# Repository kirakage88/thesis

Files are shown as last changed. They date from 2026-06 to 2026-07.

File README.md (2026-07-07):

# 🔧 Predictive Maintenance for Coiled Evaporators

> **Bachelor's Thesis** · Mechanical Engineering · Xavier University

---

## 💡 The Idea

Monitor aircon evaporator health in real time. Sensor data flows from ESP32 nodes through ESP-NOW to a TFT touchscreen, then up to the cloud. Machine learning models predict maintenance needs before failure hits.

---

## ⚡ How It Works

```
  🌡️ Sensors          📡 ESP-NOW           🖥️ TFT + ☁️ Cloud
  ┌──────────┐       ┌──────────┐        ┌──────────────┐
  │ BME280   │──────►│  Sender  │───────►│   Receiver   │
  │ DS18B20  │       │  ESP32   │  P2P   │  ESP32 + TFT │──► Supabase
  │ ×3 probes│       └──────────┘        └──────────────┘
  └──────────┘
```

**Ambient readings** (temp + humidity) + **3 probe temperatures** → calibrated → wireless → displayed + logged.

---

## 🗂️ Repo Map

```
thesis/
│
├── 📄 Thesis Proposal.pdf
│
├── 📂 codes/
│   ├── 📂 prototyping/                 # Final integrated builds
│   │   ├── ambient_module_final/       # Sensor fusion (BME280 + probes)
│   │   ├── now_ambient_sender/         # Wireless data transmitter
│   │   ├── now_receiver_supabase/      # Receiver + cloud pipeline
│   │   └── tft_complete/               # Display firmware (main UI)
│   │
│   ├── 📂 testing/                     # Component experiments
│   │   ├── BME280/  DS18B20/  probes/  i2c_scanner/
│   │   ├── now_sender/  now_receiver/  supabase/
│   │   ├── tft_display/  tft_touch/  tft_ui_demo/
│   │   └── ...                         # 15+ test sketches
│   │
│   └── 📂 python/machine learning/     # Classification experiments
│       ├── 0 perceptron.py
│       ├── 1 logistic_regression.py
│       ├── 2 SVM.py
│       ├── 3 dec_tree.py
│       ├── 4 random_forest.py
│       ├── 5 knn_classifier.py
│       └── pre-processing/
│
├── 📂 schematics/                      # Fritzing — circuits & PCBs
├── 📂 designs/                         # UI mockups, palette, fonts
└── 📂 resources/
```

---

## 🔌 Hardware

| Part | Interface | What It Does |
|---|---|---|
| ESP32-C3 Super Mini | — | Brains of the operation |
| BME280 | I2C (`0x76`) | Ambient temp + humidity |
| DS18B20 ×3 | OneWire (GPIO10) | Submerged probe temps |
| ST7789 240×320 TFT | SPI | Color display |
| XPT2046 | SPI (shared CLK) | Touch input |

### Calibration

```
BME280 Temp      →  raw × 1.0294412
BME280 Humidity  →  raw × 1.0579399
Probe A          →  1.701471 + 0.984997 × raw
Probe B / C      →  1.637417 + 0.9783362 × raw
```

---

## 🧠 Machine Learning

Six classifiers trained on sensor data — from classic Perceptron to Random Forest:

| # | Script | Model |
|---|---|---|
| 0 | `0 perceptron.py` | Perceptron |
| 1 | `1 logistic_regression.py` | Logistic Regression |
| 2 | `2 SVM.py` | Support Vector Machine |
| 3 | `3 dec_tree.py` | Decision Tree |
| 4 | `4 random_forest.py` | Random Forest |
| 5 | `5 knn_classifier.py` | K-Nearest Neighbors |

### Spin Up the Python Env

```bash
cd codes/python/machine learning

python -m venv .venv
# PowerShell:  .venv\Scripts\Activate.ps1
# Git Bash:    source .venv/Scripts/activate

pip install numpy matplotlib scikit-learn pandas

# Need deep learning later? Add PyTorch with CUDA:
pip install torch --index-url https://download.pytorch.org/whl/cu130
```

---

## 📐 Design

The TFT UI follows a **mobile-app navigation pattern** — persistent bottom bar, center arrow for a full-screen menu. Iron Grey palette with light/dark mode. Lora + Montserrat typography.

**Pages:** Main Menu → Pairing → Devices → Units → System

> Full mockups, palette shades, and component specs in `designs/tft_display/design_readme.md`.

---

## 🚀 Quick Start

**Firmware (Arduino)**
```bash
# 1. Arduino IDE + ESP32 board support
# 2. Install: TFT_eSPI, OneWire, DallasTemperature, Adafruit_BME280, esp_now, ESPSupabase
# 3. Open codes/prototyping/now_ambient_sender/
# 4. Board → ESP32-C3 Super Mini → Flash
```

**ML (Python)**
```bash
cd codes/python/machine learning
python -m venv .venv && source .venv/Scripts/activate
pip install numpy matplotlib scikit-learn pandas
python 0 perceptron.py
```

---

---

## 🛠️ Installation

**Git**
- Linux (Debian/Ubuntu): `sudo apt install git`
- macOS: `brew install git` or download from [git-scm.com](https://git-scm.com)
- ChromeOS: enable Linux (Crostini), then `sudo apt install git`
- Windows: download from [git-scm.com](https://git-scm.com)
- Verify: `git --version`

---

## ⚙️ Git Configuration

```bash
git config --global user.name "Your Name"
git config --global user.email "your_email@example.com"
git config --global init.defaultBranch main
```

- If using GitHub's privacy feature, use the provided private email: `username@users.noreply.github.com`
- Verify: `git config --global user.name` and `git config --global user.email`
- **macOS:** ignore `.DS_Store` files globally to prevent metadata files from appearing in commits:

```bash
echo ".DS_Store" >> ~/.gitignore_global
git config --global core.excludesFile ~/.gitignore_global
```

---

## 🌐 GitHub Account Setup

- Use a **real email** — required for contribution tracking
- Enable privacy settings: keep email private, block CLI pushes that expose personal email
- Enable **2FA** using a TOTP app (Google Authenticator, Authy, etc.)
  - ⚠️ **Warning:** losing 2FA credentials **and** recovery codes means permanent account lockout — GitHub Support cannot restore access

---

## 🔑 SSH Key Authentication

Check for an existing key:

```bash
ls ~/.ssh/id_ed25519.pub
```

Generate a new Ed25519 key:

```bash
ssh-keygen -t ed25519 -C "your_email@example.com"
```

- Press Enter to accept the default location
- Optional: set a passphrase for extra security

Copy the public key:

```bash
cat ~/.ssh/id_ed25519.pub
```

It starts with `ssh-ed25519` and ends with `username@hostname`.

**Add to GitHub:**
1. Settings → SSH and GPG keys → New SSH Key
2. Paste the public key as an **Authentication Key**

Test the connection:

```bash
ssh -T git@github.com
```

- Success: `"Hi username! You've successfully authenticated, but GitHub does not provide shell access."`
- Failure: retry or ask for help in TOP Discord

Multiple SSH keys can be linked to one GitHub account — one per machine.

---

*Built with ☕ and late nights by **Kira (JRon)** · JPSME-XUC · Xavier University*

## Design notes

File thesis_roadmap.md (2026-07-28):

# Thesis Roadmap — Predictive Maintenance for Coiled Evaporators

Group: John Ronald Pacaldo · Collin Brandon Asio · Simon France Sulibio

**Architecture Decision:** Unsupervised anomaly detection (primary) \+ supervised classification (secondary, conditional). \[See appendix for full A vs B analysis.\]

---

## Legend

| Emoji | Type |
| :---- | :---- |
| 📝 | Paper Overhaul |
| 🔧 | Prototyping |
| 💻 | Coding |
| 🤖 | Machine Learning |
| 📊 | Data Collection |
| 🚀 | Deployment |
| 📋 | Documentation |

| Priority | Symbol |
| :---- | :---- |
| Critical | 🔴 |
| High | 🟠 |
| Medium | 🟡 |
| Low | 🟢 |

| Status | Symbol |
| :---- | :---- |
| Not started | ⬜ |
| In progress | 🔄 |
| Blocked | 🚫 |
| Completed | ✅ |

---

## Phase 1 — Paper Overhaul: Foundation

**Goal:** Rewrite Chapter 1 and pre-prototyping sections of Chapter 3 to reflect the reframed thesis: non-invasive anomaly detection as a complementary triage tool for scheduled preventive maintenance. Lock down the architecture before any hardware work.

### Chapter 1 — Introduction

- [x] 🔴 **Rewrite the thesis title** — `1.1 JOHN PACALDO`  
        
- [x] 🔴 **Rewrite the research gap** — `1.1 JOHN PACALDO`  
        
      \- \*\*Old:\*\* "No localized data-driven early warning exists; current maintenance is insufficient."    
        
      \- \*\*New:\*\* "Scheduled preventive maintenance ensures regular cleaning every 3–4 months, but the interval between services creates an information gap: maintenance staff cannot reliably identify which specific units are experiencing early-stage performance degradation between visits without physical disassembly. This study investigates whether a non-invasive sensor system — using only external temperature, electrical, and vibration measurements, with no evaporator access — can detect anomalous operating behavior, serving as a complementary triage tool to existing preventive maintenance at Xavier University. As Xavier University develops its Campus of the Future, this study serves as a proof-of-concept for site-specific, non-invasive AC condition monitoring."  
        
- [ ] 🔴 **Fix variable-sensor mapping** — `1.4 Conceptual Framework SIMON SULIBIO`  
        
      \- Remove: refrigerant leaks (no gas sensor), ice build-up (non-invasive access constraint), ESP32-CAM (cannot open evaporator)    
        
      \- Rename: "noise" → "vibration" (MPU6050 accelerometer)    
        
      \- Add: set temperature (manually recorded from thermostat/remote during each visit) — provides baseline for comparing actual vs. target cooling performance    
        
      \- Create explicit mapping table: Independent Variable → Sensor → Data Type → Model Input    
        
      \- Redraw conceptual framework diagram to match actual hardware and non-invasive approach  
        
- [ ] 🔴 **Add operational definition of Normal/Abnormal** — `1.1 / 3.1 COLLIN ASIO`  
        
      \- A unit is \*\*Normal\*\* if it exhibits acceptable cooling performance, no abnormal vibration or electrical behavior during inspection, and no maintenance concern is documented in the PPO maintenance logs.    
        
      \- A unit is \*\*Degraded\*\* if technician inspection identifies performance degradation, abnormal electrical or vibration characteristics, or a maintenance record documents a fault requiring corrective action.  
        
- [ ] 🔴 **Rewrite research questions for unsupervised focus** *`JOHN PACALDO`*  
        
      \- \*\*RQ1:\*\* Which non-invasive sensor measurements (supply-return temperature differential, compressor/fan current signatures, vibration spectral features) demonstrate the strongest discriminatory power for distinguishing normal from degraded unit behavior, as measured by feature importance and anomaly score separation?    
        
      \- \*\*RQ2:\*\* Which unsupervised anomaly detection model (Autoencoder, Isolation Forest, One-Class SVM, Gaussian Mixture Model) most reliably identifies AC units exhibiting anomalous operating signatures, validated through retrospective log comparison and controlled fault injection?    
        
      \- \*\*RQ3 (conditional):\*\* Does replacing raw environmental sensor features with a composite thermal comfort metric (PMV) improve anomaly detection sensitivity, provided the DIY airflow sensor is successfully developed?    
        
      \- \*\*RQ4:\*\* Does anomaly score generalize across AC units not seen during model development (unit-level evaluation), and does time-since-last-cleaning confound anomaly detection?  
        
- [ ] 🔴 **Rewrite hypotheses (falsifiable with margins and tests)** *`JOHN PACALDO`*  
        
      Each RQ has at least one hypothesis. Tests: Mann-Whitney U (p\<0.05) for group separation; paired bootstrap (p\<0.05) for feature contribution; TPR threshold for raw detection rate; within 3pp/5pp for performance margins; McNemar's (p\>0.05) for model equivalence; Spearman's ρ (p\>0.05) for confound correlation; ANOVA (p\>0.05) for kit-to-kit consistency.  
        
      \*\*RQ1 — Sensor measurement discriminatory power:\*\*  
        
      \- \*\*H1a:\*\* At least one sensor measurement group (supply-return temperature differential, compressor/fan current signatures, vibration spectral features) demonstrates statistically significant anomaly score separation between known-fault and known-healthy units (p \< 0.05, Mann-Whitney U test).  
        
      \- \*\*H1b:\*\* Vibration-derived features (spectrogram CNN output or statistical features) contribute statistically significant improvement to anomaly detection over temperature-and-electrical-only features (p \< 0.05, paired bootstrap).  
        
      \*\*RQ2 — Unsupervised model performance:\*\*  
        
      \- \*\*H2a:\*\* At least one unsupervised model (Autoencoder, Isolation Forest, One-Class SVM, Gaussian Mixture Model) achieves anomaly score separation between known-fault and known-healthy units (p \< 0.05, Mann-Whitney U test) AND true positive rate ≥ 80% on injected faults.  
        
      \- \*\*H2b:\*\* PCA-reduced features achieve anomaly detection performance within 3 percentage points of the full feature set AND show no statistically significant difference in unit-level anomaly ranking (p \> 0.05, McNemar's test).  
        
      \*\*RQ3 — Composite thermal comfort metric (conditional):\*\*  
        
      \- \*\*H3 (conditional):\*\* Replacing raw environmental sensor features with a single PMV composite metric does not significantly degrade anomaly detection performance (within 3pp of raw-feature baseline).  
        
      \*\*RQ4 — Generalization and confound verification:\*\*  
        
      \- \*\*H4a:\*\* Anomaly score separation on held-out units (Leave-One-Unit-Out evaluation) remains within 5 percentage points of in-sample performance (McNemar's test, p \> 0.05).  
        
      \- \*\*H4b:\*\* Time-since-last-cleaning and ambient environmental variables (temperature, humidity) show no statistically significant correlation with anomaly score (p \> 0.05, Spearman's ρ), and kit ID does not predict anomaly score (p \> 0.05, ANOVA).  
        
      \*\*Hypothesis Execution Order & Dependencies\*\* (for planning; draft stays in RQ reading order):  
        
      \*\*First to test — H1a (gate):\*\* If no sensor group separates known-fault from known-healthy, the entire sensor suite is in question. Test with a baseline model \+ Layer 1 retrospective data before investing in Phase 7 CNN / PCA / PMV.  
        
      | \# | H | Prerequisite | Earliest phase | Test |  
        
      |---|----|-------------|---------------|------|  
        
      | 1 | H1a | 1 trained baseline model \+ Layer 1 retrospective data (13 known-fault units from PPO logs) | Phase 8 start (or pilot in Phase 6\) | Mann-Whitney U, p\<0.05 |  
        
      | 2 | H2a (Mann-Whitney half) | All 4 models trained on known-fault scores (same data as H1a) | Phase 8, parallel with H1a | Mann-Whitney U, p\<0.05 |  
        
      | 3 | H2b | Best model trained on full \+ PCA-reduced features | Phase 8, after baseline trained | McNemar's p\>0.05 \+ within 3pp |  
        
      | 4 | H1b | Phase 7 vibration features ready (CNN or statistical) | Phase 8, after Phase 7 done | Paired bootstrap, p\<0.05 |  
        
      | 5 | H2a (TPR half) | Layer 2 fault injection data scored by trained models | Phase 8 Layer 2 | TPR ≥ 80% |  
        
      | 6 | H4a | Finalized model \+ Leave-One-Unit-Out loop | Phase 8 | McNemar's p\>0.05 \+ within 5pp |  
        
      | 7 | H4b | Anomaly scores \+ confound metadata (days-since-cleaning, ambient, kit ID) | Phase 8 Layer 4 | Spearman's ρ, ANOVA, p\>0.05 |  
        
      | 8 | H3 (conditional) | DIY airflow sensor built \+ PMV computed per trial | Phase 8, last | within 3pp (sensor fails → H3 dropped) |  
        
- [ ] 🔴 **Reframe positioning as complementary triage** — `1.1 COLLIN ASIO`  
        
      \- Explicitly state: this system does NOT replace scheduled preventive maintenance. It is a diagnostic layer that flags which units need attention between cleanings, helping the PPO prioritize inspections.    
        
      \- Reference the maintenance logs as evidence that faults have been observed between scheduled cleanings (e.g., "13-MAR-23 LEAK REPAIR & REPLACEMENT OF OUTDOOR FAN MOTOR").    
        
      \- Pitch as proof-of-concept for Campus of the Future implementation.  
        
- [ ] 🟠 **Strengthen RA 11285 rationale** — `1.1 SIMON SULIBIO`  
        
      \- Add quantified energy savings estimate: "30 units × avg 2.5kW × 2,000 hrs/yr × 6.4% fouling penalty (Niknami et al., 2024\\) × ₱12/kWh ≈ ₱115,000 annual waste. Early detection could reduce this."  
        
- [ ] 🟠 **Update scope and limitations for non-invasive approach** — `1.5 SIMON SUILBIO`  
        
      \- Scope: non-invasive external sensors only; 30-40 units across 3 locations; weekly visits with 2 portable kits (proof-of-concept phase); anomaly detection as triage tool. \*\*Long-term vision:\*\* permanent sensor module installed per AC unit (Campus of the Future), continuously monitoring with automated anomaly alerts — this thesis validates the core approach.    
        
      \- Acknowledge: cannot directly observe evaporator coil condition; model detects proxy signals, not faults themselves; weekly sampling may miss transient failures between visits; portable kit mounting introduces measurement variability (mitigated by standardized protocol \\+ kit ID tracking).    
        
      \- State explicitly: fault injection during validation is part of experimental design, not operational deployment. The deployed system remains non-invasive; invasive inspection is only for labeling during the study and for controlled fault injection.  
        
- [ ] 🟡 **Justify unsupervised over supervised** — `1.5 or 3.3 COLLIN ASIO`  
        
      \- Walk the reader through the data constraint: 13 known-problem units out of 2,599 campus-wide. In a 30-40 unit sample, expect 0-3 naturally occurring Abnormal observations. Supervised classification with 0-3 positive examples is statistically unvalidatable.    
        
      \- Unsupervised anomaly detection trains on abundant normal data (\\\~95%+ of data), learns the operating envelope, and flags deviations — matching the triage framing exactly.    
        
      \- Mention: supervised classification will be tested as a secondary experiment IF controlled fault injection produces enough labeled samples (30+).  
        
- [ ] 🟢 **Add scope diagram** — `1.5 SIMON SULIBIO`  
        
      \- Visual: in scope vs. out of scope. Non-invasive anomaly detection as focus.

### Chapter 3 — Methodology (Pre-Prototyping Sections)

- [ ] 🔴 **Clarify monitoring regime** — `3.1.1 COLLIN ASIO`  
        
      \- \*\*Weekly visits with 2 portable sensor kits.\*\* One location per day, rotating through 30-40 units across SBM-AVR, College of Engineering, and Faber Hall.    
        
      \- Each visit: 10 trials per unit. Each trial: 1 minute of continuous readings at 10 Hz \\= 600 samples/sensor/trial.    
        
      \- Rename "6-month monitoring" to "6-month study with weekly measurements" throughout.  
        
- [ ] 🔴 **Add sampling parameters table** — `3.1.5 COLLIN ASIO`  
        
      \- Per sensor: sampling rate (Hz), trial duration, readings per trial, total data per unit per visit.    
        
      \- BME280/DS18B20/ACS712/ZMPT101B: 10 Hz × 60s \\= 600 samples/trial × 9 sensors \\= 5,400 readings/unit/visit.    
        
      \- MPU6050: 100 Hz × 60s \\= 6,000 samples/trial → converted to spectrogram images.  
        
- [ ] 🔴 **Nested: 🔧 Hardware BOM finalization** — `3.1.4 COLLIN ASIO`  
        
      \- 2× Thermal Node kits: ESP32-C3 \\+ BME280 (I2C 0x76) \\+ 3× DS18B20 (OneWire GPIO10).    
        
      \- 2× Electrical/Vibration Node kits: ESP32-C3 \\+ 2× ACS712 \\+ ZMPT101B \\+ MPU6050.    
        
      \- 2× Master ESP32 (receiver, ESP-NOW → Serial).    
        
      \- 2× TFT display (ST7789 240×320, optional).    
        
      \- Per-unit cost estimate and sourcing plan.  
        
- [ ] 🔴 **Add unsupervised methodology justification** — `3.3 COLLIN ASIO`  
        
      \- Primary: 4 unsupervised models (Autoencoder, Isolation Forest, One-Class SVM, GMM).    
        
      \- Autoencoder: learns to reconstruct normal sensor readings; reconstruction error above threshold \\= anomaly.    
        
      \- Isolation Forest: isolates anomalous points efficiently; non-parametric, suited to mixed feature types.    
        
      \- One-Class SVM: learns decision boundary around normal data; kernel-based.    
        
      \- GMM: probabilistic model; likelihood scores for anomaly scoring.    
        
      \- Secondary (conditional): RF, XGBoost, RBF SVM if fault injection produces ≥30 labeled samples. Drop k-NN and DNN from primary lineup.  
        
- [ ] 🟠 **Add system architecture diagram** — `3.1.4 COLLIN ASIO`  
        
      \- 2 node types (Thermal \\+ Electrical/Vibration) → Master ESP32 (ESP-NOW) → Laptop/Server (Serial) → CSV → preprocessing pipeline.    
        
      \- No ESP32-CAM, no Frost Node, no Wi-Fi image upload.    
        
      \- Power source per node, communication paths, data flow.  
        
- [ ] 🟠 **Address ESP32-C3 ADC limitations** — `3.1.4 COLLIN ASIO`  
        
      \- Document ESP32-C3 ADC noise (ENOB \\\~9-10 bits) for ACS712 analog readings.    
        
      \- Mitigation: averaging 1,000+ samples per reading; consider external 16-bit ADC (ADS1115) if onboard proves insufficient. Acknowledge as limitation if using onboard ADC.  
        
- [ ] 🟠 **Define labeling and validation protocol** — `3.1.6 COLLIN ASIO`  
        
      \- \*\*Training (unsupervised):\*\* No labels needed. All sensor data used for training.    
        
      \- \*\*Validation (layered):\*\*    
        
        \- Layer 1: Retrospective comparison against 13 known-fault units from maintenance logs (deploy kit for 1-2 visits, check anomaly score separation). Mann-Whitney U test, p \\\< 0.05.    
        
        \- Layer 2: Controlled fault injection on 2-3 units (block return air, reduce refrigerant, misalign fan). Anomaly score must rise post-injection. Target ≥ 80% true positive rate.    
        
        \- Layer 3: Monthly technician spot-checks on 5-8 units. Correlate findings with anomaly scores. Target ≥ 70% agreement.    
        
        \- Layer 4: Confound verification — anomaly score must NOT be driven by weather, time-since-cleaning, or kit-to-kit variation.    
        
        \- Layer 5: Maintenance reset — if cleaned unit's anomaly score drops post-cleaning, strongest possible evidence of real signal.    
        
      \- \*\*Supervised secondary experiment (conditional):\*\* If fault injection yields ≥30 labeled samples, train RF/XGBoost/SVM. Report macro-F1. Use Group K-Fold (unit-level splits).  
        
- [ ] 🟡 **Add power management plan** — `3.1.4 COLLIN ASIO`  
        
      \- Power source per node (USB power bank, wall outlet, or AC unit tap).    
        
      \- Battery life estimate for portable operation.    
        
      \- Sleep/wake cycles if needed for energy optimization.  
        
- [ ] 🟡 **Define sensor failure protocol** — `3.1.5 COLLIN ASIO`  
        
      \- DS18B20 disconnect → flag row, continue remaining sensors, log error.    
        
      \- MPU6050 no reading → flag trial, attempt re-read, max 3 attempts.    
        
      \- Malformed readings → log, skip, alert.  
        
- [ ] 🟡 **Standardize portable kit mounting protocol** — `3.1.5 COLLIN ASIO`  
        
      \- Document exact probe placement per sensor type.    
        
      \- Include Kit ID as a model development feature (to detect kit-driven bias), exclude from final model.    
        
      \- Verify kit-to-kit calibration before each deployment day.  
        
- [ ] 🟡 **Add time-since-last-cleaning covariate** — `3.1.5 COLLIN ASIO`  
        
      \- Extract cleaning dates from PPO maintenance logs for each unit.    
        
      \- Compute days since last cleaning for each visit.    
        
      \- Include as model feature during development; test whether anomaly score is confounded by cleaning recency.

---

## Phase 2 — Prototyping: Hardware Validation

**Goal:** Assemble and test 2 complete portable sensor kits. Verify all sensors read correctly, ESP-NOW communication is stable, and the Master ESP32 outputs structured CSV data.

### Sensor Nodes

- [ ] 🔴 **🔧 Assemble Thermal Node prototype (×2)** — `ambient_module_final/`  
        
      \- ESP32-C3 \\+ BME280 (I2C 0x76) \\+ 3× DS18B20 (OneWire GPIO10).    
        
      \- Verify all 4 sensors read simultaneously.    
        
      \- Apply calibration factors as hardcoded constants.    
        
      \- Serial output: \`Temp=XX.X Hum=XX.X Counter=X A=XX.X B=XX.X C=XX.X\`.  
        
- [ ] 🔴 **🔧 Assemble Electrical/Vibration Node prototype (×2)**  
        
      \- ESP32-C3 \\+ 2× ACS712 \\+ ZMPT101B \\+ MPU6050.    
        
      \- Verify current and voltage readings with reference DMM at XU ME/EE labs.    
        
      \- Measure and record zero-current offset for both ACS712 channels.    
        
      \- Test MPU6050 vibration capture at 100 Hz; verify spectrogram conversion.  
        
- [ ] 🔴 **🔧 Verify MPU6050 calibration offsets**  
        
      \- From calibration CSV: AX\\\_BIAS \\= \\-0.005124, AY\\\_BIAS \\= \\-0.265409, AZ\\\_BIAS \\= 0.379842.    
        
      \- Apply in firmware as hardcoded constants.

### ESP-NOW Communication

- [ ] 🔴 **🔧 ESP-NOW master-slave pairing**  
        
      \- 2 senders (Thermal, Electrical/Vibration) → 1 Master ESP32.    
        
      \- Test channel scanning via SSID \`PLDTHOMEFIBRd2228\`; fallback channel 11\\.    
        
      \- Verify MAC addresses: Sender 1 \`E0:72:A1:72:22:94\`, Sender 2 \`E0:72:A1:72:29:00\`, Receiver \`E0:72:A1:6F:F8:6C\`.    
        
      \- Test 3-second send interval stability over 1-hour continuous run.    
        
      \- \*\*ESP-NOW receive callback must only set a flag\*\* (\`volatile bool newDataReady\`). Processing runs in \`loop()\` — never in ISR.  
        
- [ ] 🟠 **🔧 Timestamp synchronization protocol**  
        
      \- Master broadcasts sync pulse → both nodes timestamp readings.    
        
      \- Verify both nodes report same timestamp within ±50ms tolerance.  
        
- [ ] 🟡 **🔧 Data struct validation**  
        
      \- Verify \`EspNowPacket\` struct (type \\+ 6 floats) matches across all nodes.    
        
      \- Test edge cases: NaN values, sensor disconnect (default to 0.0 or \\-999.0).

### TFT Display UI (Optional)

- [ ] 🟡 **🔧 TFT complete UI** — `tft_complete/`  
      \- ST7789 240×320 SPI \+ XPT2046 touch.  
      \- Pages: Main Menu → Pairing → Devices → Units → System.  
      \- Display live sensor data from Master ESP32 via Serial/UART.

### Firmware Coding

- [ ] 🔴 **💻 Calibration factor integration**  
        
      \- Embed verified calibration constants in all sensor sketches:    
        
        \- BME280: \`T\_cal \= T\_raw × 1.0294412\`, \`H\_cal \= H\_raw × 1.0579399\`    
        
        \- DS18B20 A: \`1.701471 \+ 0.984997 × raw\`    
        
        \- DS18B20 B/C: \`1.637417 \+ 0.9783362 × raw\`    
        
        \- MPU6050: apply AX/AY/AZ bias offsets    
        
      \- ACS712: \`ADC\_raw − ADC\_Zero\_Offset\` → calibrated current via sensitivity factor.  
        
- [ ] 🟠 **💻 Data formatting script**  
        
      \- Master ESP32 outputs structured CSV line: \`timestamp,unit\_id,set\_temp,temp,humid,pressure,inlet,outlet,coil,comp\_current,fan\_current,voltage,accel\_x,accel\_y,accel\_z\`.    
        
      \- Ingest script: reads Serial, validates format and ranges, writes to \`02\_Data/raw/\` with naming convention: \`YYYYMMDDTHHmmSSZ\_\<Location\>\_\<UnitID\>\_\<TrialNum\>\_RAW.csv\`.

### Nested Paper Tasks

- [ ] 🟡 **📝 Update Chapter 3** from prototyping learnings  
      \- Record actual vs. expected sensor accuracy.  
      \- Document hardware substitutions and deviations from plan.  
      \- Update system architecture diagram with final wiring and confirmed sensor lineup.

---

## Phase 3 — Paper Overhaul: Literature & Gaps

**Goal:** Overhaul Chapter 2 (RRL) with a synthesis matrix, replacement of tangential studies, and alignment with the unsupervised anomaly detection methodology.

### Chapter 2 — Review of Related Literature

- [ ] 🔴 **📝 Add synthesis matrix** — `2.11 (new section)`  
        
      \- Multi-dimensional comparison table: Study | Model | Dataset size | Accuracy | Sensor types | HVAC type | Deployment context | Limitation.    
        
      \- Column for supervised vs. unsupervised approach.    
        
      \- Write 3-5 explicit research gaps this thesis addresses, including: "limited application of unsupervised anomaly detection in non-invasive HVAC condition monitoring using low-cost external sensors."  
        
- [ ] 🔴 **📝 Replace tangential studies**  
        
      \- Remove 2.8 (Aji et al., magnetic sensors — not HVAC).    
        
      \- Remove 2.9 (Abood et al., electromechanical motors — not HVAC).    
        
      \- Replace with:    
        
        \- Study on unsupervised anomaly detection for building/HVAC systems (expand Bouabdallaoui et al., 2021 — 2.5).    
        
        \- Study on low-cost sensor calibration for predictive maintenance.    
        
        \- Study on evaporator coil fouling detection via proxy signals (expand Niknami et al., 2024 — already cited in Chapter 1).  
        
- [ ] 🟠 **📝 Reconcile calibration formula with literature**  
        
      \- Fix Probe B regression output in Chapter 4: either update R output screenshot or correct stated formula. Verify all calibration formulas match firmware codebase exactly.    
        
      \- Fix Probe A data error (\`17.3\` → \`27.3\`) in appendix.  
        
- [ ] 🟡 **📝 Cite foundational ML papers**  
        
      \- Breiman (2001) for Random Forest. Chen & Guestrin (2016) for XGBoost. Cortes & Vapnik (1995) for SVM. Liu et al. (2008) for Isolation Forest. Schölkopf et al. (2001) for One-Class SVM.    
        
      \- Don't rely solely on Sarker (2021) for all algorithm descriptions.  
        
- [ ] 🟡 **📝 Add conceptual framework diagram from literature**  
        
      \- Visual: literature findings → informs this thesis architecture.    
        
      \- Highlight unique contribution: ESP32 \\+ ESP-NOW \\+ low-cost external sensors \\+ unsupervised anomaly detection as triage tool.

### Nested ML Tasks

- [ ] 🟠 **🤖 Final model selection with justification**  
      \- **Primary (unsupervised):** Autoencoder (deep learning; reconstruction error), Isolation Forest (tree-based; non-parametric; well-suited to small-medium data), One-Class SVM (kernel-based; comparison baseline), GMM (probabilistic; confidence scores).  
      \- **Secondary (supervised, conditional):** RF, XGBoost, RBF SVM — only if fault injection produces ≥30 labeled samples. Justification: supervised comparison experiment validates whether labeled data improves over unsupervised when labels are available.  
      \- **Dropped:** k-NN (rarely competitive at this sample size), DNN (insufficient training data — require hundreds to thousands of labeled examples), ESP32-CAM CNN (removed — non-invasive constraint).

---

## Phase 4 — Sensor Calibration: Remaining Sensors

**Goal:** Complete calibration of ACS712 and ZMPT101B sensors using equipment available at XU ME/EE labs. Build the calibration database for automated CCF application.

### ACS712 Current Calibration

- [ ] 🔴 **📊 Zero-offset calibration** — both ACS712 channels  
        
      \- Node powered on, no load connected.    
        
      \- 1,000 ADC readings over 60 seconds per sensor.    
        
      \- Compute: \`ADC\_Zero\_Offset \= mean(1,000 readings)\`.    
        
      \- Store per-sensor UID in calibration database (\`01\_Sensor\_Calibration/\`).  
        
- [ ] 🔴 **📊 Sensitivity (gain) calibration**  
        
      \- Connect known resistive loads: 50W, 200W, 250W bulbs.    
        
      \- Measure True-RMS current with reference DMM at XU ME/EE labs.    
        
      \- Linear regression per sensor: \`I\_actual \= m × (ADC\_raw − ADC\_Zero\_Offset) \+ c\`.    
        
      \- If non-linear at low currents (fan motor range 0-1A) → use piecewise or polynomial fit.

### ZMPT101B Voltage Calibration

- [ ] 🔴 **📊 Trimpot standardization**  
        
      \- Adjust onboard potentiometer: 250V input → ADC output \\\~640 (below saturation, provides headroom).    
        
      \- Standardize across both Electrical/Vibration Node kits.  
        
- [ ] 🔴 **📊 3rd-order polynomial calibration**  
        
      \- Variac: 10 voltage setpoints from 50V to 250V.    
        
      \- Record ADC reading vs. True-RMS DMM reference.    
        
      \- Fit 3rd-order polynomial per module: \`V\_actual \= a₀ \+ a₁·ADC \+ a₂·ADC² \+ a₃·ADC³\`.    
        
      \- Report R² and max absolute error.

### Calibration Database

- [ ] 🟠 **💻 Calibration database script**  
        
      \- JSON per sensor type: \`{UID: {type: "linear"|"polynomial", coefficients: \[...\]}}\`.    
        
      \- Version control in \`01\_Sensor\_Calibration/\`.    
        
      \- Python helper: \`apply\_ccf(uid, raw\_value) → calibrated\_value\`.  
        
- [ ] 🟡 **💻 Automated CCF application**  
        
      \- Preprocessing pipeline reads raw CSV → looks up UID → applies CCF → writes to \`02\_Data/interim/\`.    
        
      \- Unit test: known raw value → verify calibrated output matches expected.

### Nested Paper Tasks

- [ ] 🟠 **📝 Write Chapter 4 sensor calibration results**  
      \- Per sensor: scatter plot (sensor vs. reference with regression line \+ 95% CI band).  
      \- Per sensor: residual plot. Q-Q plot for residual normality.  
      \- Report R², RMSE, max error on held-out validation set (80/20 train/val split per sensor type).  
      \- Include uncertainty discussion: residual std error per sensor, whether accuracy is sufficient for anomaly detection.  
      \- Fix Probe A data error (`17.3` → `27.3`) before any analysis.  
      \- Reconcile Probe B formula (regression output must match stated formula in Ch4 and firmware).

---

## Phase 5 — Paper Overhaul: Methodology Details

**Goal:** Condense the \~40-page textbook content in Chapter 3.3. Replace supervised classification architectures with unsupervised anomaly detection model definitions. Define validation strategy in detail.

- [ ] 🔴 **📝 Condense Chapter 3.3 Model Development section**  
        
      \- Cut textbook content: move linear regression, gradient descent, backpropagation derivations to Appendix.    
        
      \- Keep in main text: 1-2 paragraph summary per model \\+ architecture specification table.  
        
- [ ] 🔴 **📝 Define unsupervised model architectures**  
        
      \- \*\*Autoencoder:\*\* Input (9 sensor features: set\\\_temp \\+ 8 calibrated sensor readings) → Encoder (Dense 64 ReLU → Dense 32 ReLU → Dense 16 latent) → Decoder (Dense 32 ReLU → Dense 64 ReLU → Dense 9 linear). Reconstruction error (MSE) as anomaly score. Threshold: 95th percentile of training reconstruction error.    
        
      \- \*\*Isolation Forest:\*\* n\\\_estimators \\\[100, 200, 500\\\], contamination \\\[auto, 0.01, 0.05, 0.10\\\], max\\\_samples \\\[256, auto\\\]. Anomaly score: path length.    
        
      \- \*\*One-Class SVM:\*\* kernel \\\[RBF\\\], nu \\\[0.01, 0.05, 0.10\\\], gamma \\\[scale, auto, 0.01, 0.1\\\]. Anomaly score: signed distance from decision boundary.    
        
      \- \*\*GMM:\*\* n\\\_components \\\[1, 2, 3, 5, 10\\\] (selected via BIC). Anomaly score: negative log-likelihood.  
        
- [ ] 🔴 **📝 Define CNN spectrogram anomaly detection architecture**  
        
      \- Input: MPU6050 vibration → spectrogram image (time-frequency representation).    
        
      \- Architecture: Transfer learning (MobileNetV2 pretrained on ImageNet), fine-tuned on vibration spectrograms.    
        
      \- Approach: Convolutional Autoencoder — learns to reconstruct spectrograms of normal vibration patterns. Reconstruction error above threshold \\= anomalous vibration.    
        
      \- Vibration anomaly score → concatenated with sensor features in final anomaly model OR used as a multimodal anomaly detection branch.    
        
      \- Explicitly justify ImageNet weights: not an external HVAC dataset — a general-purpose computer vision foundation model, which is standard practice.  
        
- [ ] 🟠 **📝 Specify hyperparameter search space** per model  
        
      \- Isolation Forest: n\\\_estimators \\\[100, 200, 500\\\], contamination \\\[0.01, 0.05, 0.10\\\].    
        
      \- One-Class SVM: nu \\\[0.01, 0.05, 0.10\\\], gamma \\\[scale, auto, 0.01, 0.1\\\].    
        
      \- GMM: n\\\_components \\\[1, 2, 3, 5, 10\\\], covariance\\\_type \\\[full, tied, diag, spherical\\\].    
        
      \- Autoencoder: latent\\\_dim \\\[8, 16, 32\\\], learning\\\_rate \\\[0.001, 0.0001\\\], epochs \\\[50, 100\\\], batch\\\_size \\\[32, 64\\\].  
        
- [ ] 🟡 **📝 Add overfitting mitigation section**  
        
      \- Autoencoder: L2 regularization, dropout in encoder, early stopping (patience=10).    
        
      \- Isolation Forest: max\\\_samples, limited tree depth.    
        
      \- One-Class SVM: nu parameter controls outlier fraction.    
        
      \- GMM: BIC for model selection.  
        
- [ ] 🟡 **📝 Define evaluation metrics for unsupervised models** — map to H1a–H4b  
        
      \- \*\*H1a \+ H2a-MW:\*\* Anomaly score separation (known-fault vs. known-healthy): Mann-Whitney U test, p\<0.05.    
        
      \- \*\*H1b:\*\* Vibration feature contribution: paired bootstrap, p\<0.05.    
        
      \- \*\*H2a-TPR:\*\* True positive rate on injected faults: ≥ 80%. False positive rate on known-healthy: ≤ 15%.    
        
      \- \*\*H2b:\*\* PCA parity: within 3pp \+ McNemar's p\>0.05.    
        
      \- \*\*H3 (conditional):\*\* PMV parity: within 3pp.    
        
      \- \*\*H4a:\*\* Unit-level generalization: within 5pp \+ McNemar's p\>0.05.    
        
      \- \*\*H4b:\*\* Confound verification: Spearman's ρ p\>0.05 (ambient, cleaning), ANOVA p\>0.05 (kit, location).    
        
      \- Precision@K and Recall@K for ranked anomaly lists (operational triage metrics).

### Nested Coding Tasks

- [ ] 🟡 **💻 Python environment setup**  
        
      \- Activate venv: \`cd "codes/python/machine learning"; python \-m venv .venv; .venv\\Scripts\\Activate.ps1\`.    
        
      \- Install deps: \`pip install \-r ../requirements.txt\`.    
        
      \- Verify: \`python \-c "import numpy, matplotlib, sklearn, pandas, torch; print('OK')"\`.  
        
- [ ] 🟡 **💻 Project scaffolding**  
        
      \- Create \`03\_Code/\` directory structure (ingest, preprocessing, modeling, evaluation subdirs).    
        
      \- Initialize Git for code tracking.    
        
      \- Create \`config.yaml\` for paths, parameters, model configs, anomaly thresholds.

---

## Phase 6 — Data Collection

**Goal:** Deploy 2 portable kits across 30-40 units at 3 locations over 6 months. Collect consistent, calibrated sensor data. Apply weekly labeling protocol for validation.

### Hardware Deployment

- [ ] 🔴 **📊 Finalize 30-40 unit sample**  
        
      \- Select units from SBM-AVR, College of Engineering, Faber Hall 1st floor.    
        
      \- Prioritize units with "With Concern" status from maintenance logs to maximize abnormal data.    
        
      \- Prioritize split-type units (CM, CT, WM types) over window-type (WRAC).    
        
      \- Pull cleaning dates from PPO maintenance logs for each selected unit.  
        
- [ ] 🔴 **📊 Weekly data collection sessions** — 6 months  
        
      \- 2 kits, one location per day, rotate through all units.    
        
      \- Each visit: 10 trials per unit.    
        
      \- Each trial: 1 minute of continuous readings at 10 Hz (sensors) \\+ 100 Hz (MPU6050).    
        
      \- Record per trial: set temperature (manually read from thermostat/remote), ambient temp, humidity, pressure, inlet/outlet/coil temp, compressor/fan current, supply voltage, 3-axis acceleration.    
        
      \- Compute time-since-last-cleaning per unit per visit from maintenance logs.  
        
- [ ] 🟠 **📊 Controlled fault injection validation** — 3 sessions during study  
        
      \- With campus facilities permission, induce controlled faults on 2-3 units per session:    
        
        \- Partially block return air grille (simulate fouling/obstruction).    
        
        \- Reduce refrigerant charge via service valve (requires licensed technician — one-time supervised procedure).    
        
        \- Misalign fan blade (simulate mechanical imbalance).    
        
      \- Protocol: baseline measurement → induce fault → post-fault measurement → restore → recovery measurement.    
        
      \- Label each phase explicitly. This creates known ground truth for model validation.  
        
- [ ] 🟠 **📊 Monthly technician spot-checks** — validation layer  
        
      \- Rotating subset: 5-8 units per month.    
        
      \- Brief visual inspection checklist: abnormal vibration, poor cooling, unusual current, excessive noise, visible external issues.    
        
      \- Record findings. Correlate with anomaly scores at end of study.

### Data Pipeline

- [ ] 🔴 **💻 Data ingestion script**  
        
      \- Reads Serial from Master ESP32.    
        
      \- Validates format (expected columns, ranges).    
        
      \- Writes to \`02\_Data/raw/\` with naming convention: \`YYYYMMDDTHHmmSSZ\_\<Location\>\_\<UnitID\>\_\<TrialNum\>\_RAW.csv\`.  
        
- [ ] 🟠 **💻 Data cleaning & CCF application**  
        
      \- Script reads \`02\_Data/raw/\` → applies CCFs from \`01\_Sensor\_Calibration/\` → validates ranges → writes to \`02\_Data/interim/\`.    
        
      \- Handles missing values: forward-fill short gaps (\\\< 5 readings), flag longer gaps with indicator column.    
        
      \- Detects and flags outliers (outside 3σ or manual engineering thresholds).  
        
- [ ] 🟠 **💻 Feature engineering** for interim → processed  
        
      \- Rolling window statistics per trial: mean, std, min, max, slope.    
        
      \- Rate-of-change features: Δ(Inlet−Outlet)/Δt, ΔCoilTemp/Δt.    
        
      \- Derived COP proxy: (Inlet − Outlet) / Compressor Current.    
        
      \- Derived target delta-T: (Set Temp − Outlet Temp) — positive delta indicates AC is meeting target; negative delta indicates degradation.    
        
      \- Vibration statistical features: RMS, peak amplitude, spectral kurtosis, dominant frequency.    
        
      \- Vibration spectrogram generation: FFT → time-frequency image saved per trial.    
        
      \- Time-since-last-cleaning: computed from maintenance log cleaning dates.    
        
      \- Kit ID: included during development, excluded from final model.  
        
- [ ] 🟡 **💻 Data validation dashboard** (optional)  
        
      \- Simple Streamlit page: per-unit data completeness, sensor health, weekly trial count.    
        
      \- Alerts if unit has \\\< 10 trials in a week.

### Nested Paper Tasks

- [ ] 🟡 **📝 Update Chapter 3 DMP section**  
      \- Replace theoretical DMP with actual implementation notes.  
      \- Record deviations from planned storage/backup strategy.  
      \- Document actual file counts and data volumes.

---

## Phase 7 — Machine Learning: Vibration CNN

**Goal:** Train a convolutional autoencoder on MPU6050 vibration spectrograms to detect anomalous vibration patterns. This output feeds into the main unsupervised anomaly detection models.

- [ ] 🔴 **🤖 Generate vibration spectrogram dataset**  
        
      \- Per trial: MPU6050 100 Hz × 60s \\= 6,000 samples → FFT spectrogram image.    
        
      \- \\\~240 spectrograms per unit over 6 months (24 visits × 10 trials). 35 units × 240 ≈ 8,400 spectrograms total.    
        
      \- Organize: train on normal-condition units (majority), validate on known-fault \\+ injected-fault units.  
        
- [ ] 🔴 **🤖 Train convolutional autoencoder**  
        
      \- Architecture: MobileNetV2 encoder (pretrained ImageNet weights) → latent bottleneck → decoder.    
        
      \- Loss: MSE reconstruction error.    
        
      \- Save best model (lowest val\\\_loss) as \`cnn\_vibration\_autoencoder.pth\`.    
        
      \- Output per spectrogram: reconstruction error (anomaly score) \\+ latent feature vector.  
        
- [ ] 🟠 **🤖 Vibration anomaly detection evaluation** *(feeds H1b)*  
        
      \- Test on injected-fault units: reconstruction error must increase significantly post-fault vs. pre-fault.    
        
      \- Test on known-fault units from maintenance logs: reconstruction error should be higher than fleet average.    
        
      \- Report: true positive rate on injected faults, anomaly score separation (Mann-Whitney U).  
        
      \- Output ready for Phase 8 H1b ablation: CNN reconstruction error \+ latent vector extracted per trial.  
        
- [ ] 🟡 **🤖 Ablation study** (if time permits)  
        
      \- Compare: pretrained MobileNetV2 encoder vs. custom CNN from scratch.    
        
      \- Compare: reconstruction error vs. latent feature vector as anomaly score.    
        
      \- Compare: spectrogram resolution (frequency bins, time windows).

### Nested Paper Tasks

- [ ] 🟠 **📝 Write Chapter 4 vibration CNN results**  
      \- Report: architecture, dataset size, training curves (loss over epochs), anomaly score distributions.  
      \- Include: sample spectrograms (normal vs. anomalous with reconstruction overlay), anomaly score distributions for known-fault vs. healthy units.

---

## Phase 8 — Machine Learning: Unsupervised Anomaly Detection

**Goal:** Train and evaluate the 4 unsupervised models on full sensor \+ vibration feature set. Compare performance. Run the conditional supervised secondary experiment if fault injection yields enough labeled data.

### Preprocessing Pipeline

- [ ] 🔴 **🤖 Complete preprocessing pipeline**  
        
      \- Implementation in \`03\_Code/2\_preprocessing/\`.    
        
      \- Features: set\\\_temp \\+ 8 calibrated sensor readings \\+ vibration anomaly score from CNN \\+ vibration statistical features (RMS, kurtosis, peak frequency) \\+ time-since-last-cleaning.    
        
      \- Standardization: fit on normal-condition units only, transform all data.    
        
      \- PCA: fit on normal-condition units; plot variance explained; select k with ≥ 95% cumulative variance.    
        
      \- Output: X\\\_all, metadata (unit\\\_id, timestamp, kit\\\_id, location) saved to \`02\_Data/processed/\`.  
        
- [ ] 🟠 **🤖 Feature importance analysis**  
        
      \- Univariate Mann-Whitney U: which features differentiate known-fault from known-healthy units.    
        
      \- Permutation importance (using Isolation Forest as reference model).    
        
      \- Report: top 5 most discriminative features, effect sizes, p-values.

### Model Training

- [ ] 🔴 **🤖 Train Isolation Forest**  
        
      \- Hyperparameter tuning via grid search (contamination, n\\\_estimators, max\\\_samples).    
        
      \- Save \`isolation\_forest.pkl\`.    
        
      \- Feature importance: which features drive isolation.  
        
- [ ] 🔴 **🤖 Train One-Class SVM**  
        
      \- Hyperparameter tuning via grid search (nu, gamma, kernel).    
        
      \- Scale features before training (SVM is distance-sensitive).    
        
      \- Save \`one\_class\_svm.pkl\`.  
        
- [ ] 🔴 **🤖 Train Gaussian Mixture Model**  
        
      \- Select n\\\_components via BIC (test 1-10 components).    
        
      \- Save \`gmm.pkl\`.    
        
      \- Report: per-component means (interpretable "normal operating modes").  
        
- [ ] 🔴 **🤖 Train Autoencoder**  
        
      \- PyTorch implementation.    
        
      \- Architecture per Phase 5 definition.    
        
      \- Early stopping (patience=10 on validation reconstruction loss).    
        
      \- Save \`autoencoder.pth\`.

### Model Evaluation

- [ ] 🔴 **🤖 Layer 1 — Retrospective log validation** *(H1a \+ H2a-MW)*  
        
      \- Deploy kit to known-fault units (1-2 visits each).    
        
      \- \*\*H1a:\*\* Anomaly score separation per sensor measurement group (supply-return temp differential, compressor/fan current signatures, vibration spectral features) between known-fault and known-healthy units. Mann-Whitney U, p \\\< 0.05.  
        
      \- \*\*H2a-MW:\*\* All 4 models tested for anomaly score separation between known-fault and known-healthy units. Mann-Whitney U, p \\\< 0.05.  
        
      \- Report: mean anomaly score per group, effect size (Cohen's d).  
        
- [ ] 🔴 **🤖 H2b — PCA parity test**  
        
      \- Train best model on full features and on PCA-reduced features (k components with ≥ 95% cumulative variance).    
        
      \- Compare: |TPR\_full − TPR\_PCA| ≤ 3 percentage points.    
        
      \- McNemar's test on binary classification outcomes (above/below threshold): p \\\> 0.05 → no significant difference → PCA is viable.    
        
- [ ] 🟠 **🤖 H1b — Vibration ablation (paired bootstrap)**  
        
      \- Requires Phase 7 vibration features (CNN reconstruction error \+ latent vector, or statistical: RMS, kurtosis, peak frequency).    
        
      \- Train two model variants of the best model: temperature+electrical only vs. temperature+electrical+vibration. Same hyperparameters.    
        
      \- Compute performance metric (AUC or TPR) on held-out validation set for both variants.    
        
      \- Paired bootstrap (1,000+ resamples): compute performance gap per resample. If 95%+ of gaps \\\> 0 → p \\\< 0.05 → vibration contributes significantly.    
        
- [ ] 🔴 **🤖 Layer 2 — Controlled fault injection validation** *(H2a-TPR)*  
        
      \- Run all 4 models on pre-fault → post-fault → recovery data.    
        
      \- \*\*H2a-TPR:\*\* Anomaly score must rise post-injection for each fault type. True positive rate ≥ 80% across injected faults.    
        
      \- False positive rate on known-healthy fleet ≤ 15%.  
        
- [ ] 🔴 **🤖 Layer 4 — Confound verification** *(H4b)*  
        
      \- Assemble per-unit metadata: anomaly score, time-since-last-cleaning, ambient temp, ambient humidity, kit ID, location.    
        
      \- \*\*Spearman's ρ:\*\* anomaly score vs. days-since-cleaning, ambient temp, ambient humidity. All p \\\> 0.05 → no correlation.    
        
      \- \*\*ANOVA:\*\* anomaly score across kit IDs and locations. p \\\> 0.05 → no kit/location bias.    
        
      \- If any confound correlates → include it as a model feature, retrain, report both (with and without).  
        
- [ ] 🟠 **🤖 Layer 3 — Technician agreement**  
        
      \- Monthly spot-check findings vs. anomaly scores.    
        
      \- Report: agreement rate, Cohen's Kappa.  
        
- [ ] 🟠 **🤖 Layer 5 — Maintenance reset**  
        
      \- For units cleaned mid-study: anomaly score pre-cleaning vs. post-cleaning.    
        
      \- Expect: significant drop post-cleaning.    
        
      \- Report: paired t-test or Wilcoxon signed-rank.  
        
- [ ] 🟠 **🤖 Model comparison** *(answers H2a — which model wins?)*  
        
      \- Comparison table: Isolation Forest vs. One-Class SVM vs. GMM vs. Autoencoder.    
        
      \- Metrics: TPR on injected faults, FPR on healthy fleet, anomaly score separation (effect size), agreement with technician.    
        
      \- Ranking: which model performs best overall? Report per H2a: at least one must achieve p\<0.05 (Mann-Whitney) AND TPR ≥80%.  
        
- [ ] 🟠 **🤖 H4a — Unit-level generalization (Leave-One-Unit-Out)**  
        
      \- LOUO evaluation: for each unit U, train on all other units, score U. Repeat for all units.    
        
      \- Compare TPR (or AUC) on held-out units vs. in-sample units: |performance gap| ≤ 5 percentage points.    
        
      \- McNemar's test comparing in-sample vs. held-out binary outcomes: p \\\> 0.05 → no significant difference → model generalizes.    
        
      \- Report: does performance degrade significantly vs. random split? If yes → model is learning unit identities, not fault signatures.  
        
- [ ] 🟡 **🤖 H3 (conditional) — PMV composite metric comparison**  
        
      \- Requires: DIY airflow sensor built and functional. If sensor fails → H3 and RQ3 silently dropped.    
        
      \- Compute PMV per trial (temp, humidity, airflow, radiant temp).    
        
      \- Train model on PMV-only features vs. raw environmental features. Best model from comparison.    
        
      \- Compare TPR/AUC: |performance\_gap| ≤ 3 percentage points → PMV is a viable alternative.  

### Conditional Secondary: Supervised Classification

- [ ] 🟡 **🤖 IF fault injection yields ≥ 30 labeled samples**  
      \- Train: RF, XGBoost, RBF SVM on labeled subset (fault-injected \+ known-fault \+ known-healthy).  
      \- Split: Group K-Fold by unit ID (all readings from one unit in same fold).  
      \- Report: macro-F1, per-class precision/recall, confusion matrix.  
      \- Compare: does supervised classification with labels outperform unsupervised anomaly detection? If yes → strong evidence for labeled-data value. If no → unsupervised is genuinely better for this problem.  
      \- **Do NOT** run if \< 30 labeled samples; this experiment is conditional and its absence is documented.

### Nested Paper Tasks

- [ ] 🟠 **📝 Write Chapter 4 anomaly detection results**  
      \- Per hypothesis: statistical test results, effect sizes, p-values (H1a, H1b, H2a, H2b, H3-if-conditional, H4a, H4b).  
      \- Per layer: validation results table summarizing which hypotheses were tested by which layer.  
      \- Model comparison table with all metrics.  
      \- Confound verification: Spearman's ρ results, ANOVA results.  
      \- Feature importance: top discriminative sensor readings.  
      \- Interpretation: which model is recommended and why.

---

## Phase 9 — Deployment

**Goal:** Build the Streamlit dashboard and automated anomaly scoring pipeline. Deploy on the Ingest Server for live use during the final month of the study.

> **Note:** Current deployment (thesis) uses a single ingest server with manual weekly data collection via portable kits. The long-term vision (Campus of the Future) is a permanently-installed sensor module per AC unit streaming continuously to a centralized server.

### Server Setup

- [ ] 🔴 **🚀 Ingest Server configuration**  
        
      \- Set up dedicated PC or laptop with Python environment.    
        
      \- Configure Wi-Fi network (same as Master ESP32).    
        
      \- Install: Python 3.11+, watchdog, streamlit, joblib, pandas, numpy, scikit-learn, pytorch, sqlite3.    
        
      \- Set up directory structure from DMP.  
        
- [ ] 🔴 **💻 Ingest service script**  
        
      \- Reads Serial from Master ESP32.    
        
      \- Validates and writes to \`02\_Data/raw/\`.    
        
      \- Runs as persistent background process.

### Anomaly Scoring Pipeline

- [ ] 🔴 **🚀 Watchdog automation setup**  
        
      \- Monitor \`02\_Data/raw/\` for new files (use staging directory \\+ atomic move to prevent race conditions).    
        
      \- Trigger on new complete CSV → load → apply CCFs → preprocess → load best model → compute anomaly score → store result.  
        
- [ ] 🔴 **💻 Automated anomaly scoring script**  
        
      \- Load best model (e.g., \`isolation\_forest.pkl\`).    
        
      \- Load scaler \\+ PCA transformer (fit during Phase 8).    
        
      \- Process: set\\\_temp \\+ 8 sensor readings → calibrated → standardized → PCA → model.anomaly\\\_score().    
        
      \- Store: \`{unit\_id, timestamp, anomaly\_score, sensor\_snapshot}\` → \`anomalies.db\`.    
        
      \- Error handling: catch NaN, malformed input, shape mismatch → log error → skip file.  
        
- [ ] 🟠 **🚀 SQLite anomalies database**  
        
      \- Schema: \`anomalies\` table (id, unit\\\_id, timestamp, anomaly\\\_score, model\\\_name, sensor\\\_json).    
        
      \- Schema: \`alerts\` table (id, unit\\\_id, timestamp, severity, anomaly\\\_score\\\_threshold\\\_exceeded, acknowledged).    
        
      \- Create indexes on unit\\\_id, timestamp for query performance.  
        
- [ ] 🟡 **💻 Alert threshold logic**  
        
      \- Anomaly score in top 5% of training distribution → warning.    
        
      \- Anomaly score in top 1% → alert.    
        
      \- 3 consecutive alerts for same unit → critical (flag for immediate inspection).    
        
      \- Configurable via \`config.yaml\`.

### Dashboard

- [ ] 🟠 **🚀 Streamlit dashboard — main status page**  
        
      \- \`app.py\` with overview: all 30-40 units, most recent anomaly score each.    
        
      \- Color-coded grid: 🟢 Normal (below 95th percentile) / 🟠 Warning (95-99th) / 🔴 Alert (above 99th).    
        
      \- Auto-refresh every 30 seconds or triggered by watchdog file event.  
        
- [ ] 🟠 **🚀 Streamlit dashboard — unit detail page**  
        
      \- Dropdown: select unit by ID.    
        
      \- Historical chart: sensor time-series (temp, current, voltage) \\+ anomaly score overlay.    
        
      \- Anomaly history: date → anomaly score → alert status.    
        
      \- Time-since-last-cleaning indicator.  
        
- [ ] 🟡 **🚀 Streamlit dashboard — admin page**  
        
      \- Model retraining trigger button.    
        
      \- Data collection status (units not visited this week).    
        
      \- Alert acknowledgment UI.  
        
- [ ] 🟡 **💻 Streamlit authentication** (optional)  
        
      \- Simple password protection via environment variable or config.    
        
      \- Read-only view for maintenance staff, admin view for researchers.

### Cloud Sync (Optional)

- [ ] 🟢 **🚀 Supabase cloud backup**  
      \- Nightly sync script: `anomalies.db` → Supabase.  
      \- Ensure API key is NOT stored in plaintext (use environment variable).

### Nested Paper Tasks

- [ ] 🟠 **📝 Finalize Chapter 3 deployment section**  
      \- Replace theoretical deployment plan with implementation summary.  
      \- Include: architecture diagram, technology choices, deployment workflow.  
      \- Add dashboard screenshots in Appendix.

---

## Phase 10 — Finalization

**Goal:** Complete all writing, integrate results, format for submission, and prepare defense.

### Chapter 4 — Complete Results & Discussion

- [ ] 🔴 **📝 Integrate all Chapter 4 subsections**  
        
      \- 4.1 Sensor calibration (BME280, DS18B20, ACS712, ZMPT101B).    
        
      \- 4.2 Vibration CNN spectrogram anomaly detection results.    
        
      \- 4.3 Dataset overview (feature statistics, PCA results, unit-level distributions, time-since-cleaning profiles).    
        
      \- 4.4 Unsupervised anomaly detection results — all 4 models.    
        
      \- 4.5 Validation layer results (retrospective logs, fault injection, technician agreement, confound checks, maintenance reset).    
        
      \- 4.6 Conditional supervised classification results (if applicable).    
        
      \- 4.7 Deployment results (dashboard screenshots, anomaly scoring latency, system uptime).  
        
- [ ] 🔴 **📝 Discussion per section**  
        
      \- Why did model X outperform model Y? Link back to literature.    
        
      \- Were the hypotheses supported? (H1a–H4b: 7 hypotheses, each with statistical test results).    
        
      \- How did the 4-layer validation strategy perform — which layers provided strongest evidence?    
        
      \- Limitations encountered (sensor noise, dataset size, sparse known-fault units, ambient confounds).    
        
      \- Implications for Xavier University maintenance practices and Campus of the Future.

### Chapter 5 — Conclusion & Recommendations

- [ ] 🟠 **📝 Write conclusions**  
        
      \- Summary of what was built and tested.    
        
      \- Answer each research question directly.    
        
      \- Key finding: which model is recommended and why.  
        
- [ ] 🟠 **📝 Write recommendations**  
        
      \- For Xavier University PPO: adopt anomaly detection as triage tool, integrate with existing quarterly maintenance cycle. Transition from portable proof-of-concept to permanent per-unit sensor modules (weatherproof enclosure, AC-powered, fixed mounting brackets, automated calibration, remote firmware updates).    
        
      \- For future research: multi-fault type classification, permanent sensor installation, regression-based degradation forecasting, mobile app, expansion to all 2,599 campus units.    
        
      \- For hardware: external ADC for ACS712, permanent mounting brackets, automated calibration protocol.

### Final Deliverables

- [ ] 🟠 **📝 Abstract** — 250-300 words.  
- [ ] 🟡 **📝 Acknowledgements**.  
- [ ] 🟡 **📝 Appendices** — calibration data tables, R regression outputs, full code listings, dashboard screenshots, maintenance log excerpts, fault injection protocols.  
- [ ] 🟡 **📋 APA/citation audit** — check all in-text citations → reference list, consistent format throughout.  
- [ ] 🟡 **📋 Table of Contents, List of Figures, List of Tables** — auto-generated.  
- [ ] 🟡 **📋 Defense presentation** — 15-20 slides.  
      \- Problem & motivation: the information gap between cleanings.  
      \- Architecture: non-invasive → 2 portable kits → ESP-NOW → anomaly detection (proof-of-concept for permanent per-unit modules on Campus of the Future).  
      \- Methodology: why unsupervised? (walk through the 13-in-2,599 math).  
      \- Key results (1 slide per major finding).  
      \- Validation: the 4-layer evidence.  
      \- Conclusions & recommendations.  
      \- Demo video of dashboard (1-2 min).

---

## Milestones & Deadlines

| Date | Milestone | Deliverables |
| :---- | :---- | :---- |
| YYYY-MM-DD | Phase 1 complete | Ch1 overhauled, Ch3 pre-proto sections, architecture locked |
| YYYY-MM-DD | Phase 2 complete | 2 portable kits assembled, ESP-NOW working, CSV output verified |
| YYYY-MM-DD | Phase 3 complete | Ch2 overhauled, synthesis matrix, literature aligned with unsupervised |
| YYYY-MM-DD | Phase 4 complete | ACS712 \+ ZMPT101B calibrated, calibration DB built, Ch4 calibration section drafted |
| YYYY-MM-DD | Phase 5 complete | Ch3 model dev section condensed, 4 unsupervised architectures defined, validation protocol documented |
| YYYY-MM-DD | Phase 6 complete | 6-month data collection, 30-40 units, fault injection sessions, technician spot-checks |
| YYYY-MM-DD | Phase 7 complete | CNN vibration autoencoder trained, evaluated, Ch4 vibration results written |
| YYYY-MM-DD | Phase 8 complete | 4 unsupervised models trained \+ evaluated, all 5 validation layers, Ch4 anomaly results written |
| YYYY-MM-DD | Phase 9 complete | Dashboard live, anomaly scoring pipeline running, Ch3 deployment finalized |
| YYYY-MM-DD | Phase 10 complete | Full thesis draft submitted for adviser review |
| YYYY-MM-DD | Defense | Presentation, demo, Q\&A |
| YYYY-MM-DD | Final submission | Hardbound copies \+ digital archive |

---

## Risk Registry

| Risk | Likelihood | Impact | Mitigation |
| :---- | :---- | :---- | :---- |
| Insufficient Abnormal data (0-3 natural faults in 6 months) | High | High | **Already mitigated** — unsupervised approach does not need Abnormal labels for training. Fault injection provides guaranteed Abnormal samples for validation. |
| Fault injection permission denied by campus facilities | Medium | High | Engage PPO early (Phase 1). Present as research collaboration, not liability. Have adviser endorse. If denied: rely on retrospective log validation \+ technician spot-checks only. |
| Calibration equipment not available at XU labs | Low | High | **Confirmed available.** Verify specific equipment access during Phase 1\. |
| DIY airflow sensor not ready in time (PMV experiment) | High | Low | **Already mitigated** — PMV is conditional. If sensor fails, H3 and RQ3 drop silently. Does not affect primary thesis contribution. |
| 30-40 units overwhelming for 2-kit weekly rotation | Medium | Medium | Start with smaller rotation (20 units), expand as process stabilizes. Document scaling challenges honestly. |
| Scope too large for 3 members | Medium | High | Cut non-critical tasks (Supabase cloud sync, TFT UI, Streamlit auth) if behind schedule. Supervised secondary experiment is conditional — drop without penalty if insufficient data. |
| Adviser feedback requires major revision | Medium | Medium | Submit drafts incrementally per phase, not all at once at end. Each phase produces a reviewable deliverable. |
| Anomaly score confounded by ambient conditions | Medium | Medium | **Mitigated by Layer 4 validation.** Include ambient temp/humidity/time-since-cleaning as control variables. Report confound checks transparently. |
| CNN spectrogram approach fails (data volume, domain mismatch) | Medium | Medium | **Fallback:** vibration statistical features (RMS, kurtosis, peak frequency) as tabular features. CNN is attempted but not required for thesis success. |

---

## Assignment Legend

| Abbreviation | Name |
| :---- | :---- |
| JRP | John Ronald Pacaldo |
| CBA | Collin Brandon Asio |
| SFS | Simon France Sulibio |

---

## Appendix: Supervised vs. Unsupervised Decision Summary

**Three LLMs independently reviewed the methodology choice. Verdict: 3-0 for Unsupervised Anomaly Detection.**

### Why Unsupervised Won

| Reason | Detail |
| :---- | :---- |
| **Math is fatal for supervised** | 13 known-problem units / 2,599 campus-wide. 0-3 Abnormal observations expected in 30-40 unit study sample. Supervised classification with 0-3 positive examples is statistically unvalidatable. |
| **Labels aren't ground truth** | Technician visual inspection is a subjective proxy — cannot see the evaporator (non-invasive). Training supervised on proxy labels \= training to reproduce noise. |
| **Matches the thesis claim** | "Flag unusual behavior → prioritize inspection" is anomaly detection, not classification. The words match the method. |
| **Handles novel failures** | Unsupervised detects ANY deviation from normal. Supervised can only detect failure modes present in training data. |

### Supervised as Conditional Secondary

If controlled fault injection produces ≥ 30 labeled Abnormal samples, run supervised classifiers (RF, XGBoost, RBF SVM) as a **comparison experiment**. This is a bonus, not a dependency. If it fails or insufficient data is produced, the unsupervised primary contribution stands alone.

### Validation Strategy

5-layer validation designed to answer "how do you prove it works without labels?":

1. **Retrospective log comparison** — anomaly score separation between known-fault and known-healthy units (Mann-Whitney U, p \< 0.05).  
2. **Controlled fault injection** — inject known faults, verify anomaly score rises (TPR ≥ 80%).  
3. **Monthly technician spot-checks** — correlate findings with anomaly scores (agreement ≥ 70%).  
4. **Confound verification** — prove anomaly score isn't driven by weather, cleaning recency, or kit variation.  
5. **Maintenance reset** — cleaned units show anomaly score drop → real signal, not noise.

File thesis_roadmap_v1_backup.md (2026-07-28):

# Thesis Roadmap — Predictive Maintenance for Coiled Evaporators

> Last updated: YYYY-MM-DD  
> Status: ███████░░░ XX% complete  
> Group: John Ronald Pacaldo · Collin Brandon Asio · Simon France Sulibio

---

## Legend

| Emoji | Type |
|---|---|
| 📝 | Paper Overhaul |
| 🔧 | Prototyping |
| 💻 | Coding |
| 🤖 | Machine Learning |
| 📊 | Data Collection |
| 🚀 | Deployment |
| 📋 | Documentation |

| Priority | Symbol |
|---|---|
| Critical | 🔴 |
| High | 🟠 |
| Medium | 🟡 |
| Low | 🟢 |

| Status | Symbol |
|---|---|
| Not started | ⬜ |
| In progress | 🔄 |
| Blocked | 🚫 |
| Completed | ✅ |

---

## Phase 1 — Paper Overhaul: Foundation

### Chapter 1 — Introduction

- [ ] 🔴 **Fix variable-sensor mapping** — `1.4 Conceptual Framework`
  - Reconcile independent variables (air temperature, noise, ice build-up, refrigerant leaks) with actual hardware
  - Either add acoustic sensor + refrigerant leak sensor to hardware plan, or remove noise/leak from framework
  - Create explicit mapping table: Variable → Sensor → Data Type → Model Input

- [ ] 🔴 **Define expert-validated labeling criteria** — `1.1 / 3.1.5`
  - Define quantitative thresholds: "Abnormal = visible frost > 20% coil surface OR inlet-outlet ΔT < 3°C OR compressor current > X A"
  - Name the experts consulted and their qualifications
  - Include criteria in the methodology section

- [ ] 🟠 **Strengthen RA 11285 rationale** — `1.1`
  - Add paragraph quantifying potential energy savings from PdM at Xavier University
  - Cite reported 6.4% energy increase from 30% fouling (Niknami et al., 2024)
  - Estimate: "N AC units × avg consumption × 6.4% × ₱/kWh = ₱X annual savings"

- [ ] 🟠 **Add testable hypotheses** — `1.2`
  - H1: At least one ML model achieves F1 ≥ 0.85 for binary normal/abnormal classification
  - H2: PCA-reduced features achieve comparable performance to full 11-feature dataset
  - H3: Hybrid CNN+RF outperforms standalone RF by ≥ 2% F1

- [ ] 🟡 **Reframe RQ3 for testability** — `1.1`
  - Current: "How can the framework integrate real-time data collection…"
  - Suggested: "What is the end-to-end latency from sensor reading to dashboard update in self-hosted vs. cloud-based deployment?"

- [ ] 🟡 **Justify binary classification choice** — `1.5`
  - Add argument: binary classification is industry standard for initial PdM; more actionable than continuous score
  - If regression is revisited later, it becomes a future work item

- [ ] 🟢 **Add scope diagram** — `1.5`
  - Visual: what's in scope (50 units, 3 locations, 6 models, binary classification) vs. out of scope (regression, multi-fault identification, mobile app)

### Chapter 3 — Methodology (Pre-Prototyping Sections)

- [ ] 🔴 **Clarify monitoring regime** — `3.1.1`
  - State explicitly: continuous installation (sensors permanently mounted) OR weekly visit protocol (portable kit, 10 trials, removed)
  - This fundamentally affects data characteristics and affects the entire downstream pipeline
  - If weekly visits: rename "6-month monitoring" to "6-month study with weekly measurements" throughout

- [ ] 🔴 **Resolve ESP32-CAM image transmission path** — `3.1.4`
  - ESP-NOW payload = 250 bytes; a single QVGA JPEG = 10–50 KB → cannot transmit images via ESP-NOW
  - Choose and document one approach:
    - Option A: On-device TinyML (quantized CNN on ESP32-CAM, send classification label only)
    - Option B: Wi-Fi HTTP/MQTT image upload to Ingest Server
    - Option C: SD card storage, manual transfer weekly
  - Recommend Option A — aligns with edge computing literature

- [ ] 🔴 **Add sampling parameters table** — `3.1.5`
  - Per sensor: sampling rate (Hz), trial duration (min), readings per trial
  - Total expected data volume per unit per visit
  - Example: BME280 @ 1 Hz × 5 min trial = 300 readings/trial

- [ ] 🟠 **Add system architecture diagram** — `3.1.4`
  - All 3 node types with sensors, power sources, communication paths
  - Data flow: Node → Master (ESP-NOW) → Ingest Server (Wi-Fi) → NAS → Cloud
  - Clearly distinguish ESP-NOW path (sensor readings) from Wi-Fi path (images/config)

- [ ] 🟠 **Address ESP32-C3 ADC limitations** — `3.1.4`
  - Document ESP32-C3 ADC noise (ENOB ~9–10 bits) for ACS712 analog readings
  - Consider external 16-bit ADC (ADS1115) or digital current sensor (INA219) for fan motor current
  - If using onboard ADC: specify averaging strategy (>1000 samples) and expected accuracy

- [ ] 🟡 **Add power management plan** — `3.1.4`
  - Power source per node (USB, battery, AC unit tap)
  - Battery life estimate if portable
  - Sleep/wake cycles for energy optimization

- [ ] 🟡 **Define sensor failure protocol** — `3.1.5`
  - DS18B20 disconnect → flag row, continue remaining sensors
  - ESP32-CAM blurry image → re-capture, max 3 attempts
  - Malformed readings → log, skip, alert

- [ ] 🔴 **Nested: 🔧 Hardware BOM finalization** — `3.1.4`
  - Finalize Bill of Materials: 50× BME280, 150× DS18B20, 100× ACS712, 50× ZMPT101B, 50× ESP32-C3, 50× ESP32-CAM
  - Per-unit cost estimate
  - Sourcing plan (orders, lead times)

---

## Phase 2 — Prototyping: Hardware Validation

### Sensor Nodes

- [ ] 🔴 **🔧 Assemble Thermal Node prototype** — `ambient_module_final/`
  - ESP32-C3 + BME280 (I2C 0x76) + 3× DS18B20 (OneWire GPIO10)
  - Verify all 4 sensors read simultaneously
  - Apply calibration factors as hardcoded constants
  - Serial monitor output format: `Temp=XX.X Hum=XX.X Counter=X A=XX.X B=XX.X C=XX.X`

- [ ] 🔴 **🔧 Assemble Electrical Node prototype**
  - ESP32-C3 + 2× ACS712 + ZMPT101B
  - Verify current and voltage readings with reference DMM
  - Measure and record zero-current offset for both ACS712 channels
  - Test with known resistive loads (50W, 200W bulbs)

- [ ] 🔴 **🔧 Assemble Frost Node prototype**
  - ESP32-CAM image capture at regular interval
  - Test image quality under various lighting conditions (HVAC unit interior)
  - Baseline image size (JPEG quality vs. file size)
  - If on-device CNN: test Edge Impulse model export → Arduino

### ESP-NOW Communication

- [ ] 🔴 **🔧 ESP-NOW master-slave pairing**
  - 3 senders (Thermal, Electrical, Frost) → 1 Master ESP32
  - Test channel scanning via SSID `PLDTHOMEFIBRd2228`; fallback channel 11
  - Verify MAC addresses: Accel `E0:72:A1:72:22:94`, Ambient `E0:72:A1:72:29:00`, Receiver `E0:72:A1:6F:F8:6C`
  - Test 3-second send interval stability over 1-hour continuous run

- [ ] 🟠 **🔧 Timestamp synchronization protocol**
  - Master broadcasts sync pulse → all nodes timestamp readings
  - Verify all 3 nodes report same timestamp within ±50ms tolerance
  - Test over 30-minute run

- [ ] 🟡 **🔧 Data struct validation**
  - Verify `EspNowPacket` struct (type + 6 floats) matches across all nodes
  - Test edge cases: NaN values, sensor disconnect (default to 0.0 or -999.0)

### TFT Display UI

- [ ] 🟡 **🔧 TFT complete UI** — `tft_complete/`
  - ST7789 240×320 SPI + XPT2046 touch
  - Pages: Main Menu → Pairing → Devices → Units → System
  - Display live sensor data from Master ESP32 via Serial/UART
  - Color palette: Iron Grey light/dark modes (macros in sketch)

### Firmware Coding

- [ ] 🔴 **💻 Calibration factor integration**
  - Embed verified calibration constants in all sensor sketches
  - BME280: `T_cal = T_raw × 1.0294412`, `H_cal = H_raw × 1.0579399`
  - DS18B20 A: `1.701471 + 0.984997 × raw`
  - DS18B20 B/C: `1.637417 + 0.9783362 × raw`
  - ACS712: `ADC − ADC_Zero_Offset` → calibrated current via sensitivity factor

- [ ] 🟠 **💻 Data formatting script**
  - Master ESP32 outputs structured CSV line: `timestamp,unit_id,temp,humid,pressure,inlet,outlet,coil,comp_current,fan_current,voltage,frost,coil_cond`
  - Ingest Server ingestion script: reads serial, validates format, writes to `02_Data/raw/`

- [ ] 🟡 **💻 Supabase integration** (optional — testing sketch)
  - Test ESP32 → Supabase insert for `readings` table
  - Verify JSON format: `{"temperature":X, "humidity":X, "counter":X, "a_temp":X, "b_temp":X, "c_temp":X}`

### Nested Paper Tasks

- [ ] 🟡 **📝 Update Chapter 3** from prototyping learnings
  - Record actual vs. expected sensor accuracy
  - Document any hardware substitutions
  - Update system architecture diagram with final wiring

---

## Phase 3 — Paper Overhaul: Literature & Gaps

### Chapter 2 — Review of Related Literature

- [ ] 🔴 **📝 Add synthesis matrix** — `2.11 (new section)`
  - Multi-dimensional comparison table: Study | Model | Dataset size | Accuracy | Sensor types | HVAC type | Deployment context | Limitation
  - Write 3–5 explicit research gaps this thesis addresses

- [ ] 🔴 **📝 Replace tangential studies**
  - Remove 2.8 (Aji et al., magnetic sensors — not HVAC)
  - Remove 2.9 (Abood et al., electromechanical motors — not HVAC)
  - Replace with:
    - Study on low-cost sensor calibration for predictive maintenance
    - Study on evaporator coil fouling detection (expand Niknami et al., 2024)
    - Study on ESP32/edge computing for building monitoring

- [ ] 🟠 **📝 Reconcile calibration formula with literature**
  - Fix Probe B regression output: either update R output screenshot or correct formula
  - Ensure all calibration formulas in Chapter 4 match firmware codebase exactly

- [ ] 🟡 **📝 Cite foundational ML papers**
  - Add: Breiman (2001) for Random Forest, Chen & Guestrin (2016) for XGBoost, Cortes & Vapnik (1995) for SVM
  - Don't rely solely on Sarker (2021) for all algorithm descriptions

- [ ] 🟡 **📝 Add conceptual framework diagram from literature**
  - Visual showing: literature findings → informs this thesis's architecture
  - Highlight unique contribution: ESP32 + ESP-NOW + low-cost sensors + hybrid CNN+RF

### Nested ML Tasks

- [ ] 🟠 **🤖 Final model selection**
  - Confirm: RF, XGBoost, k-NN, RBF SVM, DNN, Hybrid CNN+RF
  - Add justification paragraph for each (why included, why not others)
  - Consider adding Logistic Regression as baseline (simplest interpretable model)

---

## Phase 4 — Sensor Calibration: Remaining Sensors

### ACS712 Current Calibration

- [ ] 🔴 **📊 Zero-offset calibration** — both ACS712 channels
  - Node powered on, no load connected
  - 1000 ADC readings over 60 seconds per sensor
  - Compute: `ADC_Zero_Offset = mean(1000 readings)`
  - Store per-sensor UID in calibration database (`01_Sensor_Calibration/`)

- [ ] 🔴 **📊 Sensitivity (gain) calibration**
  - Connect known resistive loads: 50W, 200W, 250W bulbs
  - Measure True-RMS current with reference DMM (Fluke 115 or equivalent)
  - Linear regression per sensor: `I_actual = m × (ADC_raw − ADC_Zero_Offset) + c`
  - If non-linear at low currents → use piecewise or polynomial fit

### ZMPT101B Voltage Calibration

- [ ] 🔴 **📊 Trimpot standardization**
  - Adjust onboard potentiometer: 250V input → ADC output ~640 (below saturation)
  - Standardize across all 50 modules

- [ ] 🔴 **📊 3rd-order polynomial calibration**
  - Variac: 10 voltage setpoints from 50V to 250V
  - Record ADC reading vs. True-RMS DMM reference
  - Fit 3rd-order polynomial per sensor: `V_actual = a₀ + a₁·ADC + a₂·ADC² + a₃·ADC³`
  - Report R² and max absolute error

### Calibration Database

- [ ] 🟠 **💻 Calibration database script**
  - JSON or CSV per sensor type: `{UID: {type: "linear"|"polynomial", coefficients: [...]}}`
  - Version control the calibration database in `01_Sensor_Calibration/`
  - Python helper: `apply_ccf(uid, raw_value) → calibrated_value`

- [ ] 🟡 **💻 Automated CCF application**
  - Preprocessing pipeline reads raw CSV → looks up UID → applies CCF → writes to `02_Data/interim/`
  - Includes unit test: known raw value → verify calibrated output matches expected

### Nested Paper Tasks

- [ ] 🟠 **📝 Write Chapter 4 sensors calibration results**
  - Include figure: scatter plot per sensor (sensor vs. reference with regression line)
  - Include figure: residual plot per sensor
  - Report R², RMSE, max error on held-out validation set (80/20 split)
  - Fix Probe A data error (`17.3` → `27.3`) before analysis
  - Reconcile Probe B formula (regression output vs. stated formula)

---

## Phase 5 — Paper Overhaul: Methodology Details

- [ ] 🔴 **📝 Condense Chapter 3.3 Model Development section**
  - Cut ~40 pages of textbook content (linear regression, gradient descent, backpropagation derivations)
  - Move mathematical derivations to an Appendix
  - Keep in main text: 1–2 paragraph summary per model + architecture specification table

- [ ] 🔴 **📝 Define DNN architecture**
  - Input layer: 11 features (or k PCA components)
  - Hidden layers: e.g., Dense(64, ReLU) → Dropout(0.3) → Dense(32, ReLU) → Dropout(0.3)
  - Output layer: Dense(1, Sigmoid) for binary classification
  - Loss: Binary Cross-Entropy
  - Optimizer: Adam, learning rate 0.001
  - Batch size: 32, epochs: 100 (early stopping patience 10)

- [ ] 🔴 **📝 Define CNN architecture**
  - Input: e.g., 224×224×3 (or native ESP32-CAM resolution)
  - Architecture: Transfer learning (MobileNetV2 or custom)
    - Conv2D(32, 3×3) → MaxPool(2×2) → Conv2D(64, 3×3) → MaxPool(2×2) → Conv2D(128, 3×3) → MaxPool(2×2) → Flatten → Dense(128) → Dropout(0.5) → Dense(2, Softmax)
  - Loss: Categorical Cross-Entropy
  - Data augmentation: random horizontal flip, ±10% brightness, ±10° rotation
  - Batch size: 16, epochs: 50 (early stopping patience 10)

- [ ] 🔴 **📝 Define Hybrid CNN+RF architecture**
  - Two-stage pipeline:
    - Stage 1: ESP32-CAM image → CNN → frost probability [0,1] + coil condition probability [0,1]
    - Stage 2: 9 sensor features + 2 CNN probabilities → Random Forest → normal/abnormal
  - Alternative: CNN penultimate layer (128-dim feature vector) + 9 sensor features → RF
  - Include architecture diagram

- [ ] 🟠 **📝 Specify hyperparameter search space** per model
  - RF: n_estimators [50, 100, 200, 500], max_depth [5, 10, 20, None], min_samples_leaf [1, 2, 5]
  - XGBoost: n_estimators [100, 300, 500], max_depth [3, 6, 9], learning_rate [0.01, 0.1, 0.3]
  - k-NN: k [3, 5, 7, 9, 11], metric [euclidean, manhattan], weights [uniform, distance]
  - SVM: C [0.1, 1, 10, 100], gamma [scale, auto, 0.01, 0.1]
  - DNN: layers [1, 2, 3], neurons [32, 64, 128], dropout [0.2, 0.3, 0.5], lr [0.001, 0.0001]

- [ ] 🟡 **📝 Add overfitting mitigation section**
  - DNN/CNN: Dropout, L2 regularization, early stopping, batch normalization
  - RF: max_depth, min_samples_leaf, n_estimators
  - SVM: C (regularization), gamma (kernel width)
  - k-NN: k selection, distance weighting

### Nested Coding Tasks

- [ ] 🟡 **💻 Python environment setup**
  - Activate venv: `cd "codes/python/machine learning"; python -m venv .venv; .venv\Scripts\Activate.ps1`
  - Install deps: `pip install -r ../requirements.txt`
  - Verify: `python -c "import numpy, matplotlib, sklearn, pandas, torch; print('OK')"`

- [ ] 🟡 **💻 Project scaffolding**
  - Create `03_Code/` directory structure (ingest, preprocessing, modeling subdirs)
  - Initialize Git for code tracking
  - Create `config.yaml` for paths, parameters, model configs

---

## Phase 6 — Data Collection

### Hardware Deployment

- [ ] 🔴 **📊 Deploy sensor nodes to 50 AC units**
  - SBM-AVR: ~15 units
  - College of Engineering: ~25 units
  - Faber Hall 1st floor: ~10 units
  - Install, test connectivity, assign UnitID

- [ ] 🔴 **📊 Weekly data collection sessions** — 6 months
  - Each visit: 10 trials per unit per week
  - Each trial: X minutes of continuous readings at specified sampling rate
  - Record: ambient temp, humidity, pressure, inlet/outlet/coil temp, compressor/fan current, voltage
  - Also: One ESP32-CAM still image per trial (or N images)

- [ ] 🔴 **📊 Image labeling** — frost / coil condition
  - Label each image: Normal / Frost present / Fouled coils / Both
  - Expert validation: have HVAC technician/PE verify a random 10% sample
  - Compute inter-rater agreement (Cohen's Kappa) if multiple labelers

### Data Pipeline

- [ ] 🔴 **💻 Data ingestion script**
  - Reads serial/MQTT from Master ESP32
  - Validates format (expected columns, ranges)
  - Writes to `02_Data/raw/` with naming convention: `YYYYMMDDTHHmmSSZ_<Location>_<UnitID>_<TrialNum>_RAW.csv`

- [ ] 🟠 **💻 Data cleaning & CCF application**
  - Script reads `02_Data/raw/` → applies CCFs from `01_Sensor_Calibration/` → validates ranges → writes to `02_Data/interim/`
  - Handles missing values: forward-fill short gaps (<5 readings), flag longer gaps
  - Detects and flags outliers (outside 3σ or manual thresholds)

- [ ] 🟠 **💻 Feature engineering** for interim → processed
  - Rolling window statistics per trial: mean, std, min, max, slope
  - Rate-of-change features: Δ(Inlet−Outlet)/Δt, ΔCoilTemp/Δt
  - Derived COP proxy: (Inlet − Outlet) / Compressor Current

- [ ] 🟡 **💻 Data validation dashboard** (optional)
  - Simple Streamlit page: per-unit data completeness, sensor health, weekly trial count
  - Alerts if unit has <10 trials in a week

### Nested Paper Tasks

- [ ] 🟡 **📝 Update Chapter 3 DMP section**
  - Replace theoretical DMP with actual implementation notes
  - Record any deviations from planned storage/backup strategy
  - Document actual file counts, data volumes

---

## Phase 7 — Machine Learning: CNN (Image Classification)

- [ ] 🔴 **🤖 Prepare image dataset**
  - Organize labeled images: train/val/test splits per class
  - Class balance check — if imbalanced, apply augmentation or weighted loss

- [ ] 🔴 **🤖 Train CNN model**
  - Implement in PyTorch or TensorFlow/Keras
  - Track training/validation loss and accuracy per epoch
  - Save best model (lowest val_loss) as `cnn_frost_classifier.pth`

- [ ] 🟠 **🤖 CNN evaluation**
  - Confusion matrix: Frost / No Frost / Fouled / Clean
  - Per-class precision, recall, F1
  - Overall accuracy
  - Confusion matrix plot

- [ ] 🟡 **🤖 Ablation study** (if time permits)
  - Compare: Transfer learning (MobileNetV2) vs. custom CNN from scratch
  - Compare: With/without data augmentation
  - Report results

- [ ] 🟡 **💻 Edge deployment (optional)**
  - If on-device: quantize model (INT8) via Edge Impulse or TensorFlow Lite
  - Export to Arduino-compatible C array
  - Benchmark inference time on ESP32-CAM

### Nested Paper Tasks

- [ ] 🟠 **📝 Write Chapter 4 CNN results**
  - Report: architecture choice, dataset size, class distribution, training curves, evaluation metrics
  - Include: confusion matrix figure, sample predictions (image + predicted label + confidence)

---

## Phase 8 — Machine Learning: Sensor Classifiers

### Preprocessing Pipeline

- [ ] 🔴 **🤖 Complete preprocessing pipeline**
  - Implementation in `03_Code/2_preprocessing/`
  - Standardization: fit on train only, transform val/test
  - One-hot encoding: frost label, coil condition label → binary columns
  - PCA: fit on train, transform val/test; plot variance explained; select k with ≥95% cumulative
  - Output: X_train, X_val, X_test, y_train, y_val, y_test saved to `02_Data/processed/`

- [ ] 🟠 **🤖 Class imbalance handling**
  - Check class distribution (Normal vs. Abnormal)
  - If ratio > 3:1, apply SMOTE on training set only
  - Report pre- and post-balancing class counts

### Model Training

- [ ] 🔴 **🤖 Train RF classifier**
  - Hyperparameter tuning via GridSearchCV (5-fold inner CV)
  - Best params → final training → save `rf_classifier.pkl`
  - Feature importance plot (top features for normal vs. abnormal)

- [ ] 🔴 **🤖 Train XGBoost classifier**
  - GridSearchCV tuning
  - Feature importance (gain, weight, cover)

- [ ] 🔴 **🤖 Train k-NN classifier**
  - k selection via elbow method (accuracy vs. k curve)
  - Test Euclidean vs. Manhattan distance

- [ ] 🔴 **🤖 Train RBF SVM classifier**
  - GridSearchCV: C, gamma
  - Note: may need subsampling if dataset > 10K rows (SVM scales quadratically)

- [ ] 🔴 **🤖 Train DNN classifier**
  - PyTorch implementation
  - Training loop with early stopping
  - Save `dnn_classifier.pth`

- [ ] 🔴 **🤖 Train Hybrid CNN+RF**
  - Feed image(s) through trained CNN → extract probabilities or penultimate features
  - Concatenate with sensor features
  - Train RF on combined feature set
  - Save `hybrid_cnn_rf.pkl`

### Model Evaluation

- [ ] 🔴 **🤖 Evaluate all models on held-out test set**
  - Per model: confusion matrix, accuracy, precision (Normal), recall (Normal), precision (Abnormal), recall (Abnormal), F1 (macro), F1 (weighted)
  - Single comparison table with all 6 models and all metrics

- [ ] 🔴 **🤖 Friedman test + Nemenyi post-hoc**
  - 30 subsets → accuracy per model per subset
  - Friedman test: H₀ rejected if p < 0.05
  - Nemenyi post-hoc: pairwise critical difference
  - CD (Critical Difference) diagram: rank models, connect non-significantly-different groups

- [ ] 🟠 **🤖 Error analysis**
  - For best model: examine misclassified samples
  - What features distinguish correctly vs. incorrectly classified samples?
  - Any systematic pattern? (e.g., all misclassifications from a specific building or unit type)

- [ ] 🟡 **🤖 Ablation study** (optional)
  - Compare: Full 11 features vs. PCA-reduced vs. sensor-only (no CNN image features)
  - Quantify contribution of image-based features to model performance

### Nested Paper Tasks

- [ ] 🟠 **📝 Write Chapter 4 ML results**
  - Results table: all 6 models × all metrics
  - CD diagram from Nemenyi test
  - Feature importance plot (RF)
  - One confusion matrix for best model
  - Interpretation: which model is best and why?

---

## Phase 9 — Deployment

### Server Setup

- [ ] 🔴 **🚀 Ingest Server configuration**
  - Set up dedicated PC or Raspberry Pi with Python environment
  - Configure Wi-Fi network (same as Master ESP32)
  - Install: Python 3.11+, watchdog, streamlit, joblib, pandas, numpy, scikit-learn, sqlite3
  - Set up NAS mount point + directory structure from DMP

- [ ] 🔴 **💻 Ingest service script**
  - Reads serial/Socket from Master ESP32
  - Validates and writes to `02_Data/raw/`
  - Runs as persistent background service (systemd or Windows Service)

### Inference Pipeline

- [ ] 🔴 **🚀 Watchdog automation setup**
  - Monitor `02_Data/raw/` for new files (use FILE_CLOSED or staging directory + atomic move)
  - Trigger on new complete CSV → load → apply CCFs → preprocess → load model → predict → store result

- [ ] 🔴 **💻 Automated inference script**
  - Load best model (`rf_classifier.pkl` or `hybrid_cnn_rf.pkl`)
  - Load scaler + PCA transformer
  - Predict: 11 features → calibrated → standardized → PCA → model.predict()
  - Store: `{unit_id, timestamp, prediction, confidence, features_snapshot}` → `predictions.db`
  - Error handling: catch NaN, malformed input, shape mismatch → log error → skip file

- [ ] 🟠 **🚀 SQLite predictions database**
  - Schema: `predictions` table with columns: id, unit_id, timestamp, prediction (0/1), confidence (float), features_json (TEXT)
  - Schema: `alerts` table with columns: id, unit_id, timestamp, severity (warning/alert/critical), acknowledged (bool)
  - Create indexes on unit_id, timestamp for query performance

- [ ] 🟡 **💻 Alert threshold logic**
  - Single abnormal → warning
  - 3 consecutive abnormals for same unit → alert
  - 5 consecutive abnormals → critical (email/SMS notification optional)
  - Configurable via `config.yaml`

### Dashboard

- [ ] 🟠 **🚀 Streamlit dashboard — main status page**
  - `app.py` with overview: all 50 units, most recent prediction each, color-coded grid (🟢 Normal / 🔴 Abnormal / ⚪ No data)
  - Auto-refresh every 30 seconds (or triggered by watchdog file event)

- [ ] 🟠 **🚀 Streamlit dashboard — unit detail page**
  - Dropdown: select unit by ID
  - Historical chart: sensor time-series (temp, current, voltage) + prediction overlay
  - Prediction history table: date → prediction → confidence

- [ ] 🟡 **🚀 Streamlit dashboard — admin page**
  - Model retraining trigger button
  - Data collection status (units that haven't reported this week)
  - Alert acknowledgment UI

- [ ] 🟡 **💻 Streamlit authentication** (optional)
  - Simple password protection via environment variable or config
  - Read-only view for maintenance staff, admin view for researchers

### Cloud Sync (Optional)

- [ ] 🟢 **🚀 Supabase cloud backup**
  - Nightly sync script: `predictions.db` → Supabase `readings` table
  - Ensure API key is NOT stored in plaintext (use environment variable)
  - Test connectivity and data integrity

### Nested Paper Tasks

- [ ] 🟠 **📝 Finalize Chapter 3 deployment section**
  - Replace theoretical deployment plan with implementation summary
  - Include: architecture diagram, technology choices, deployment workflow
  - Add dashboard screenshots in Appendix

---

## Phase 10 — Finalization

### Chapter 4 — Complete Results & Discussion

- [ ] 🔴 **📝 Integrate all Chapter 4 subsections**
  - 4.1 Sensor calibration (BME280, DS18B20, ACS712, ZMPT101B)
  - 4.2 CNN image classification results
  - 4.3 Dataset overview (class distribution, PCA results, feature statistics)
  - 4.4 ML model comparison (all 6 models, all metrics)
  - 4.5 Statistical analysis (Friedman + Nemenyi)
  - 4.6 Deployment results (dashboard screenshots, latency, uptime)

- [ ] 🔴 **📝 Discussion per section**
  - Why did model X outperform model Y? Link back to literature
  - Were the hypotheses supported? (H1: F1 ≥ 0.85, H2: PCA comparable, H3: Hybrid > RF)
  - Limitations encountered (sensor noise, dataset size, labeling subjectivity)
  - Implications for Xavier University maintenance practices

### Chapter 5 — Conclusion & Recommendations

- [ ] 🟠 **📝 Write conclusions**
  - Summary of what was built and tested
  - Answer each research question directly
  - Key finding: which model is recommended for deployment and why

- [ ] 🟠 **📝 Write recommendations**
  - For Xavier University PPO: adopt PdM for high-priority AC units, integrate into maintenance workflow
  - For future research: regression models, multi-fault classification, mobile app, longer monitoring, more sensors (acoustic, refrigerant leak)
  - For hardware: upgrade to external ADC, better power management, permanent installation

### Final Deliverables

- [ ] 🟠 **📝 Abstract** — 250–300 words
- [ ] 🟡 **📝 Acknowledgements**
- [ ] 🟡 **📝 Appendices** — calibration data tables, R regression outputs, full code listings, dashboard screenshots
- [ ] 🟡 **📋 APA/citation audit** — check all in-text citations → reference list, consistent format
- [ ] 🟡 **📋 Table of Contents, List of Figures, List of Tables** — auto-generated
- [ ] 🟡 **📋 Defense presentation** — 15–20 slides
  - Problem & motivation
  - Hardware architecture
  - Methodology overview
  - Key results (1 slide per major finding)
  - Conclusions & recommendations
  - Demo video of dashboard (1–2 min)

---

## Milestones & Deadlines

| Date | Milestone | Deliverables |
|---|---|---|
| YYYY-MM-DD | Phase 1 complete | Ch1 overhaul + Ch3 pre-proto sections |
| YYYY-MM-DD | Phase 2 complete | All 3 nodes assembled, ESP-NOW working, TFT UI functional |
| YYYY-MM-DD | Phase 3 complete | Ch2 overhaul, literature synthesis matrix |
| YYYY-MM-DD | Phase 4 complete | ACS712 + ZMPT101B calibration, calibration database built |
| YYYY-MM-DD | Phase 5 complete | Ch3 model dev section condensed, architectures defined |
| YYYY-MM-DD | Phase 6 complete | 6-month data collection, all 50 units, image labeling |
| YYYY-MM-DD | Phase 7 complete | CNN trained, evaluated, Ch4 CNN results written |
| YYYY-MM-DD | Phase 8 complete | All 6 ML models trained + evaluated, Friedman test, Ch4 ML results written |
| YYYY-MM-DD | Phase 9 complete | Dashboard live, inference pipeline running, Ch3 deployment finalized |
| YYYY-MM-DD | Phase 10 complete | Full thesis draft submitted for adviser review |
| YYYY-MM-DD | Defense | Presentation, demo, Q&A |
| YYYY-MM-DD | Final submission | Hardbound copies + digital archive |

---

## Risk Registry

| Risk | Likelihood | Impact | Mitigation |
|---|---|---|---|
| Sensor availability (350 units) delayed by supplier | Medium | High | Order early; identify backup suppliers; reduce unit count if needed |
| Calibration equipment not available at XU labs | Medium | High | Verify availability before Phase 1 end; source from partner labs; budget for rental |
| ESP32-CAM image quality poor inside AC unit | Medium | Medium | Test under real conditions early (Phase 2); add LED ring light if needed |
| Class imbalance (too few Abnormal samples) | High | Medium | Apply SMOTE; use class-weighted loss; consider semi-supervised if extreme |
| 6-month timeline insufficient for data collection | Medium | High | Prioritize units with known issues; possibly extend monitoring; reduce trial count |
| Scope too large for 3 members | High | High | Cut non-critical tasks (Supabase cloud sync, edge TinyML deployment) if behind schedule |
| Adviser feedback requires major revision | Medium | Medium | Submit drafts incrementally (per phase), not all at once at end |

---

## Assignment Legend

| Abbreviation | Name |
|---|---|
| JRP | John Ronald Pacaldo |
| CBA | Collin Brandon Asio |
| SFS | Simon France Sulibio |

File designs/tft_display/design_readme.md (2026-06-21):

## TFT Display Design Reference

ESP-NOW Aircon Controller — Thesis Project

\---

### Design Direction

Modern, minimal, abstract. Clean typography, generous whitespace, no
decorative clutter. Content-first layout with a restrained color palette.

Inspiration: [Realtime Colors](https://www.realtimecolors.com/?colors=1f1f1f-f7f7f7-333333-adadad-3f4850&fonts=Lora-Montserrat)
(Lora + Montserrat font pair), [M3 Material](https://m3.material.io/).

\---

### Color Palette — Iron Grey (RGB565)

Defined as `#define` macros in a shared `colors.h` (zero RAM, no duplication).

#### Core Defines (colors.h)

|Name|Hex|RGB565|Role|
|-|-|-|-|
|`COL\\\\\\\_BRIGHT\\\\\\\_SNOW`|`#f8f8f8`|`0xFFDF`|Background / text on dark|
|`COL\\\\\\\_SILVER`|`#cccccc`|`0xCE79`|Borders, dividers|
|`COL\\\\\\\_SILVER\\\\\\\_2`|`#aeaeae`|`0xAD75`|Disabled states|
|`COL\\\\\\\_IRON\\\\\\\_GREY`|`#474747`|`0x4228`|Primary text, dark bgs|
|`COL\\\\\\\_IRON\\\\\\\_GREY\\\\\\\_2`|`#4b5660`|`0x4AAC`|Accent, headers|

#### 

#### 

#### Light Mode

|Name|Hex|RGB565|Role|
|-|-|-|-|
|Carbon Black|`#1f1f1f`|`0x2104`|Text|
|Bright Snow|`#f8f8f8`|`0xF7BE`|Surface|
|Graphite|`#333333`|`0x31A6`|Primary|
|Silver|`#b8b8b8`|`0xCE59`|Secondary|
|Alabaster Grey|`#ebebeb`|—|Surface Container|
|Charcoal Blue|`#3f4850`|`0x424A`|Accent|

#### 

#### 

#### Dark Mode

|Name|Hex|RGB565|Role|
|-|-|-|-|
|Carbon Black|`#e0e0e0`|`0xDEFB`|Text|
|Bright Snow|`#080808`|`0x0841`|Surface|
|Graphite|`#cccccc`|`0xCE59`|Primary|
|Silver|`#333333`|`0x31A6`|Secondary|
|Charcoal Blue|`#afb8c0`|`0xADB7`|Accent|

\---

### Font Rules

All fonts are VLW, stored in PROGMEM as `.h` arrays.
Load via `loadFont()` / `unloadFont()` per screen.

|Role|Font|Size|Use|
|-|-|-|-|
|H1|Lora SemiBold|24px|Page titles, welcome heading|
|H2|Lora Regular|18px|Sub-headings, taglines|
|Emphasis|Montserrat Regular|13px|Labels, active states, button text|
|Body|Montserrat Light|13px|Descriptions, list items, secondary|

Custom fonts directory: `custom\\\\\\\_tft\\\\\\\_fonts/fontsketch/`

\---

### Navigation Model (Option B)

Mobile-app pattern: persistent bottom bar + center arrow above it
that expands a full-screen menu.

* **Bottom bar** — quick access to most-used screens (Devices, Units)
* **Center arrow** — opens full-screen menu with ALL destinations
* Bar persists on every page; active tab highlighted (accent color)
* Reserve bar height (\~40–50px): `CONTENT\\\\\\\_HEIGHT = TFT\\\\\\\_HEIGHT - BAR\\\\\\\_HEIGHT`
* No back arrow on Main Menu (it is the root)

\---

### Pages

#### 1\. Main Menu

* Logo at top center
* "Welcome" (H1) below logo
* Rotating tagline (H2) below welcome — cycles every 2–3s:

  1. "All sensors, one screen"
  2. "Monitor · Manage · Control."
  3. "Every unit, simplified"
  4. "Control every unit"
* 2×2 button grid:

|Button|Icon|Label|
|-|-|-|
|Pairing|link/wifi|Pairing|
|Devices|chip|Devices|
|Units|snowflake|Units|
|System|gear|System|

* Center arrow above bottom bar
* Persistent bottom bar

#### 2\. Pairing

* Auto-search mode + manual ESP-NOW pair
* Action buttons, dialog/popup for confirm

#### 3\. Devices List

* List view with status indicators
* Per-device send-status toggle

#### 4\. Units List

* Expand/collapse list (aircon unit → assigned ESP devices)
* Add/remove action buttons

#### 5\. System

TBD

\---

### UI Components Needed

Button grid, list view with status, expand/collapse list, toggle switch,
action buttons, dialog/popup, bottom bar, full-screen menu/drawer,
rotating tagline, logo image

\---

### Assets

Directory: `assets/`

|File|Format|Purpose|
|-|-|-|
|`ac.svg`|SVG|Aircon/Units icon|
|`chip.svg`|SVG|Devices icon|
|`pair.svg`|SVG|Pairing icon|
|`system.svg`|SVG|System/Settings icon|
|`wifi.png`|PNG|WiFi icon|

Icons: Material Symbols Outlined (Google Fonts), 24px, wght 400, GRAD 0.

Other design files:

|File|Purpose|
|-|-|
|`home\\\\\\\_page.png`|Main menu mockup|
|`init\\\\\\\_page.png`|Initialization page mockup|
|`palette\\\\\\\_shades.png`|Full palette shade reference|
|`pureref.pur`|PureRef design reference|
|`tft.af`|Affinity Designer file|

\---

### Shared Infrastructure

* **Screen manager** — owns active screen, dispatches touch, handles transitions
* **Custom fonts** — VLW in PROGMEM (`.h` arrays), 4 fonts loaded on demand
* **Color scheme** — single `#define` block in `colors.h`, shared across all screens
* **Helper functions** — `helper\\\\\\\_functions.h/.cpp` (shared `tft` via `extern`)
e.g. `drawImageCenter`, `drawIconCenter`, color/draw helpers

\---

### Design Decisions

* Modern, minimal, abstract — no decorative elements, content-first
* No back arrow on Main Menu (root page)
* Center arrow above bottom bar opens full-screen menu
* Icons + labels per button/tab (use `drawIconCenter`)
* Icon-only on bottom bar if width is tight (240px display)
* Rotating taglines cycle every 2–3 seconds
* Status indicator for ESP-NOW state (connected / searching / offline)
* Avoid clutter (battery %, time) unless load-bearing for demo

\---

### TFT\_eSPI Pinout

|TFT Pin|GPIO|
|-|-|
|VCC|5V|
|GND|GND|
|CS|7|
|RESET|3|
|DC|2|
|SDI (MOSI)|6|
|SCK|4|
|LED|3.3V|
|SDO (MISO)|5|
|T\_CLK|4|
|T\_CS|8|
|T\_DIN|6|
|T\_DO|5|
|T\_IRQ|—|

\---

### Notes

* TFT\_eSPI has no runtime image decoder/scaler. Convert PNG/JPG/SVG to
RGB565 (`pushImage`) or 1-bit XBM (`drawXBitmap`) arrays on PC first.
* Display: ST7789 240×320 via SPI
* Touch: XPT2046 via SPI (shared CLK with TFT)

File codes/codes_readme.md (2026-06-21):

## Codes Reference

ESP-NOW Aircon Controller — Thesis Project

\---

### Directory Structure

```
codes/
├── prototyping/          # Integrated prototype modules (final iterations)
│   ├── ambient\_module\_final/   # Sensor module (BME280 + DS18B20 probes)
│   ├── now\_ambient\_sender/     # ESP-NOW sender (sensor data → receiver)
│   ├── now\_receiver\_supabase/  # ESP-NOW receiver + Supabase upload
│   ├── tft\_complete/           # TFT display firmware (main UI)
│   └── libraries/              # Dependencies for prototyping sketches
└── testing/             # Individual component tests \& experiments
    ├── BME280/               # BME280 sensor test
    ├── i2c\_scanner/          # I2C address scanner
    ├── mac\_address/          # ESP32 MAC address reader
    ├── now\_sender/           # ESP-NOW sender test
    ├── now\_receiver/         # ESP-NOW receiver test
    ├── now\_sender\_web/       # ESP-NOW sender + web server
    ├── now\_receiver\_web/     # ESP-NOW receiver + web server
    ├── PROBEA/               # Temperature probe A calibration
    ├── PROBEB/               # Temperature probe B calibration
    ├── PROBEC/               # Temperature probe C calibration
    ├── probes/               # Multi-probe DS18B20 test
    ├── supabase/             # Supabase insert test
    ├── tft\_custom\_fonts/     # VLW font rendering test
    ├── tft\_display/          # TFT display init \& basic drawing
    ├── tft\_gemini/           # TFT UI experiment (Gemini-assisted)
    ├── tft\_image/            # Image rendering test (pushImage)
    ├── tft\_touch/            # Touch input test
    ├── tft\_ui\_demo/          # Full UI demo (sidebar dashboard)
    ├── web\_server/           # Async web server test
    └── libraries/            # Dependencies for testing sketches
```

\---

### Prototyping

#### ambient\_module\_final/

**Purpose:** Reads ambient temperature/humidity (BME280) and three DS18B20
probe temperatures, applies calibration, outputs to Serial.

**Sensors:**

* BME280 (I2C addr `0x76`) — ambient temp + humidity
* 3× DS18B20 (OneWire bus on GPIO10) — probe temperatures

**Calibration:**

* BME280 temp: `CAL\_FACTOR = 1.0294412` (no intercept)
* BME280 hum: `Hum\_Factor = 1.0579399` (no intercept)
* Probe A: `1.701471 + 0.984997 × raw`
* Probe B/C: `1.637417 + 0.9783362 × raw`

**Libraries:** `OneWire`, `DallasTemperature`, `Adafruit\_BME280`,
`Adafruit\_Sensor`, `Wire`

\---

#### now\_ambient\_sender/

**Purpose:** Reads all sensors (same as ambient\_module\_final) and transmits
data via ESP-NOW to a receiver ESP32.

**Data struct (`EspNowData`):**

|Field|Type|Description|
|-|-|-|
|`temp`|`float`|Calibrated BME280 temp|
|`humid`|`float`|Calibrated BME280 humidity|
|`counter`|`int`|Message counter|
|`a\_temp`|`float`|Calibrated probe A temp|
|`b\_temp`|`float`|Calibrated probe B temp|
|`c\_temp`|`float`|Calibrated probe C temp|

**Config:**

* WiFi STA mode, scans for SSID to match channel
* ESP-NOW peer: receiver MAC `14:63:93:8C:FC:78`, channel 11
* Send interval: 3 seconds
* Send callback logs success/failure

**Libraries:** `WiFi`, `esp\_now`, `esp\_wire`, `Wire`,
`Adafruit\_BME280`, `OneWire`, `DallasTemperature`

\---

#### now\_receiver\_supabase/

**Purpose:** Receives ESP-NOW data from sender, uploads to Supabase
(`readings` table).

**Flow:**

1. Connects to WiFi (SSID: `PLDTHOMEFIBRd2228`)
2. Initializes Supabase client
3. Registers ESP-NOW receive callback (stores data, sets flag)
4. On `newDataReady` flag → calls `postToSupabase()`

**Supabase:**

* Table: `readings`
* Columns: `temperature`, `humidity`, `counter`, `a\_temp`, `b\_temp`, `c\_temp`
* Inserts as JSON string via `supabase.insert()`

**Safety:** Callback only sets a flag; actual HTTP POST runs in `loop()`
context (not ISR), preventing WiFi/HTTP crashes.

**Libraries:** `WiFi`, `esp\_now`, `ESPSupabase`

\---
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

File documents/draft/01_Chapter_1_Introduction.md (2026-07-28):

# Chapter I: Introduction

## 1.1 Background of the Study

> **STAGED DRAFT — JRP's edits only. Compare against `documents/01_Chapter_1_Introduction.md`.**
>
> **Title alternatives (JRP task, needs adviser re-approval):**
>
> **Option A (primary):** DEVELOPMENT OF A PREDICTIVE MAINTENANCE FRAMEWORK USING NON-INVASIVE ANOMALY DETECTION FOR COILED EVAPORATORS IN SPLIT-TYPE AIR CONDITIONING SYSTEMS AT XAVIER UNIVERSITY – ATENEO DE CAGAYAN
>
> **Option B:** DEVELOPMENT OF A PREDICTIVE MAINTENANCE FRAMEWORK VIA NON-INVASIVE ANOMALY DETECTION FOR COILED EVAPORATORS IN SPLIT-TYPE AIR CONDITIONING SYSTEMS AT XAVIER UNIVERSITY – ATENEO DE CAGAYAN
>
> **Option C:** DEVELOPMENT OF A NON-INVASIVE ANOMALY DETECTION SYSTEM FOR PREDICTIVE MAINTENANCE OF COILED EVAPORATORS IN SPLIT-TYPE AIR CONDITIONING SYSTEMS AT XAVIER UNIVERSITY – ATENEO DE CAGAYAN
>
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

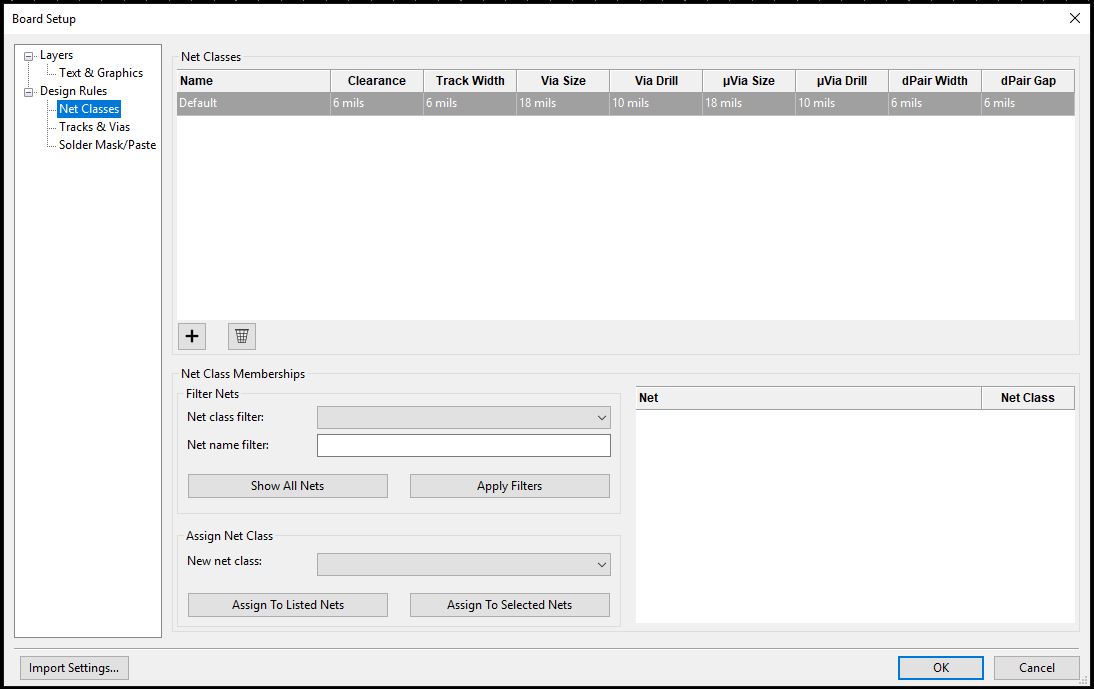
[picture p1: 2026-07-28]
schematics/kicad_templates-master/Sierra 2 layer Board/meta/Images/Net Classes.JPG

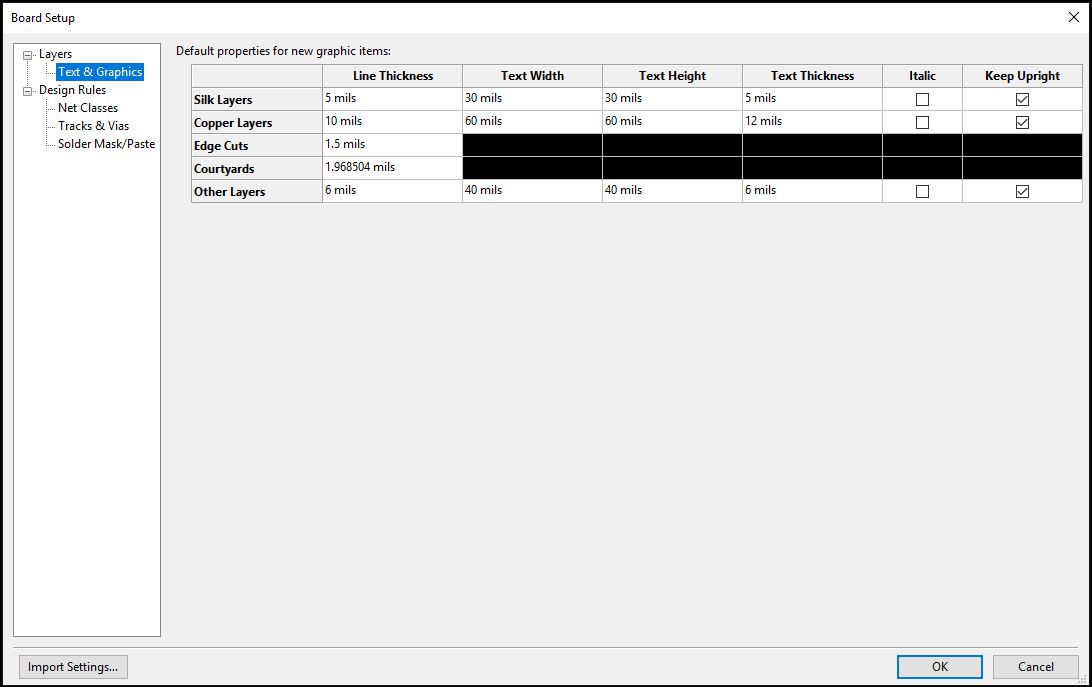
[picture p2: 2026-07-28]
schematics/kicad_templates-master/Sierra 2 layer Board/meta/Images/Text & Graphics.JPG

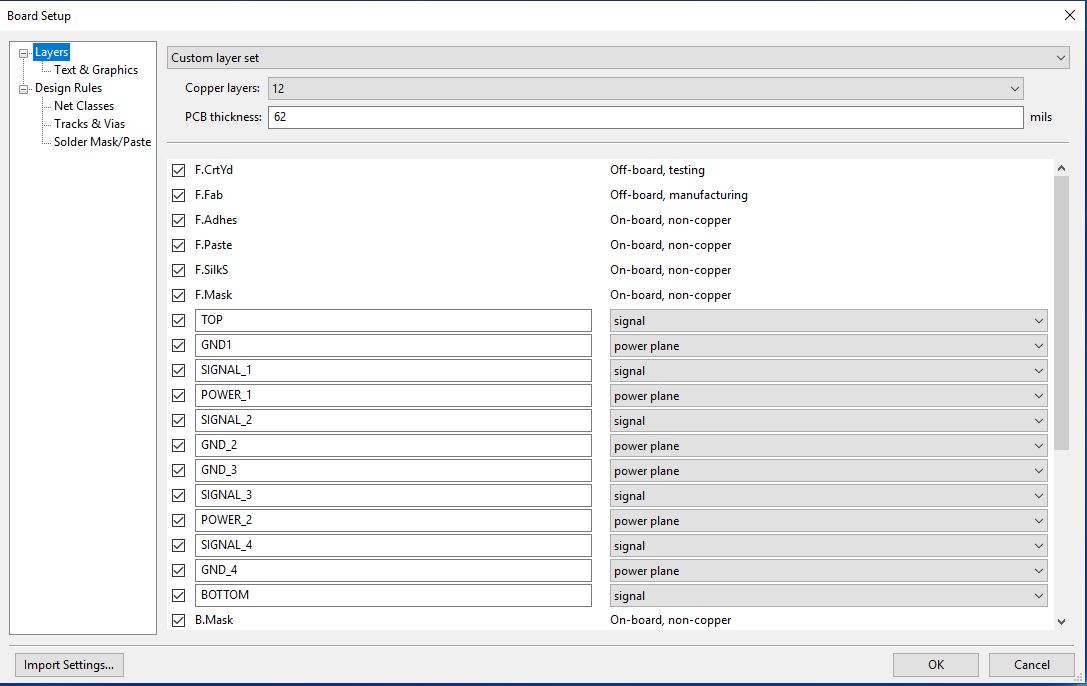
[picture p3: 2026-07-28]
schematics/kicad_templates-master/Sierra 12 layer Board/meta/Images/Layers.JPG

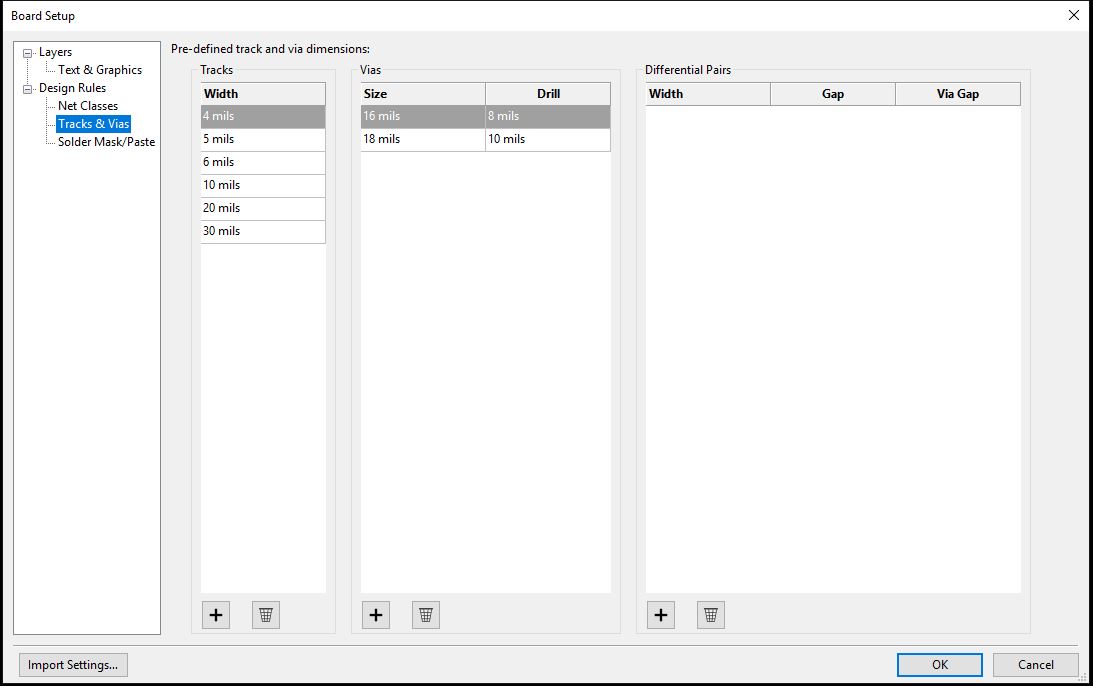
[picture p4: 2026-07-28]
schematics/kicad_templates-master/Sierra 12 layer Board/meta/Images/Trace & Vias.JPG

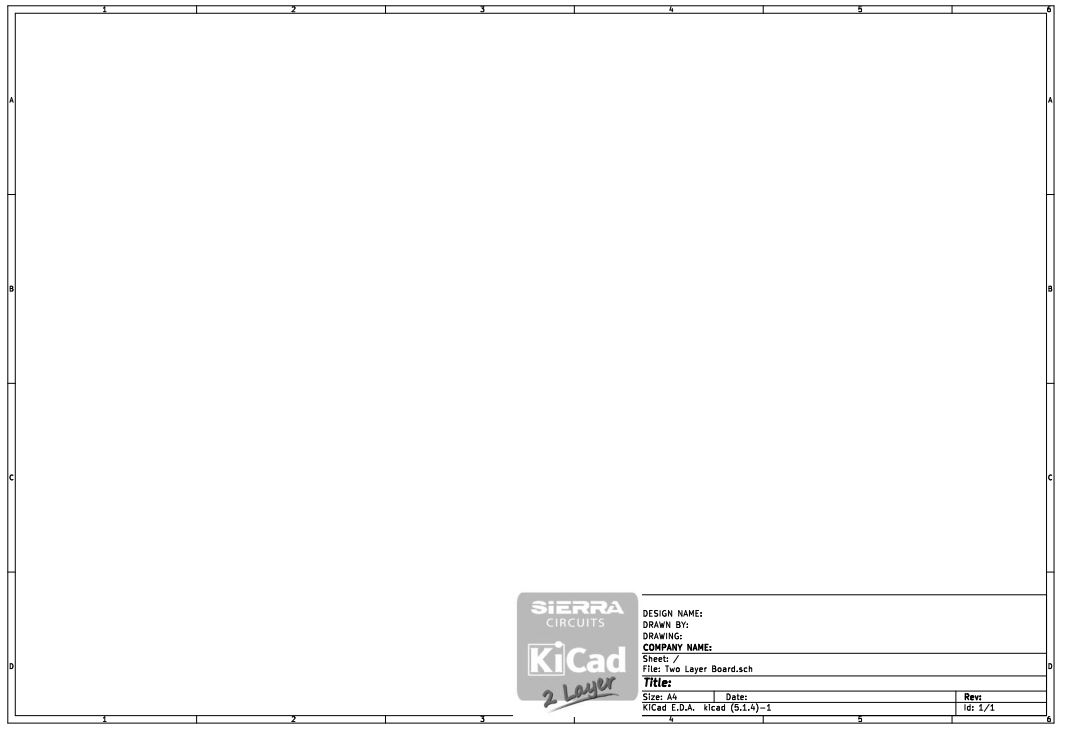
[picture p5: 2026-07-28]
schematics/kicad_templates-master/Sierra 2 layer Board/meta/Images/schematic.jpg

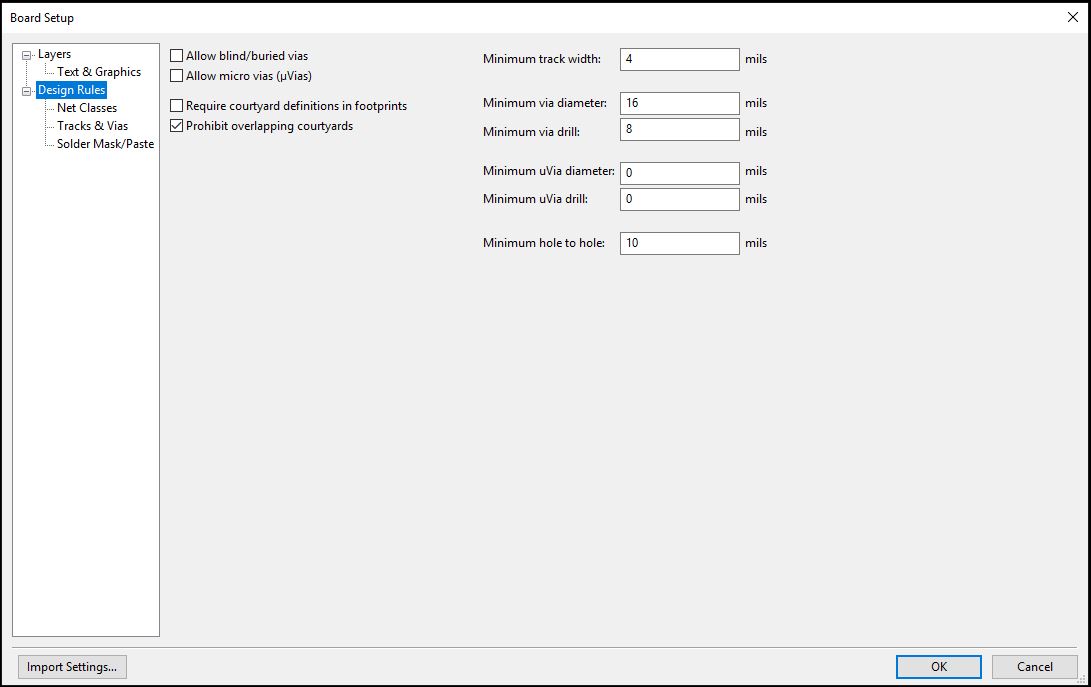
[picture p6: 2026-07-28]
schematics/kicad_templates-master/Sierra 12 layer Board/meta/Images/Design Rules.JPG

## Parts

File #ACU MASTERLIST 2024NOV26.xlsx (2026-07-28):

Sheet: MASTERLIST
Uptown | XU Main |  |  |  |  |  | CM | Ceiling Mounted | Inverter |  |  | Operational |  |  |  |  |  |  |  |  |  |  |  |  |  |  |  |  |  |  | 2023
Downtown | XU ALGCIT |  | 2024 1st Cleaning | 2024 2nd Cleaning |  |  | CT | Cassette type | Conventional |  |  | With Concern |  |  |  |  |  |  |  |  |  |  |  |  |  |  |  |  | 1st cleaning | 2nd cleaning | 3rd cleaning
 | XU Manresa |  |  |  |  |  | FM | Floor Mounted |  |  |  | Defective |  |  |  |  |  |  |  |  |  |  |  |  |  |  |  |  | june to | october to | febuary to
 | XU Pueblo |  |  |  |  |  | PACU | Precision Air Conditioning Unit |  |  |  | For Replacement |  |  |  |  |  |  |  |  |  |  |  |  |  |  |  |  | september | january | may
 | XUGS Macasandig |  |  |  |  |  | WM | Wall Mounted |  |  |  | UNDER REPAIR
 | Marine Center - Jasaan |  |  |  |  |  | WRAC | Window Room Air Conditioner
 | LOCATION DETAILS |  |  |  |  |  | AIRCON DETAILS |  |  |  |  |  |  | Cleaning Month |  |  |  |  |  |  | Cleaning Month |  |  |  |  | Cleaning Old Details |  |  |  |  |  | 2023 Repairs - 1 |  |  | 2023 Repairs - 2 |  |  | 2023 Repairs - 3 |  |  | 2024 Repairs - 1 |  |  | 2024 Repairs - 2 |  |  | 2024 Repairs - 3
GROUP | SUB-GROUP | BUILDING | # of FLOORS | FLOOR | OFFICE / ROOM # | ACU / ASSET # | Type of ACU/ # | HP/ Ton | Class | Brand | Serial # | STATUS | NOTE | 2019 Cleaning | 2020 Cleaning | 2021 Cleaning | 2022 Cleaning | 2023 2nd Cleaning | 2023 3rd Cleaning | 2023 4th Cleaning | 2024 1st Cleaning | 2024 2nd Cleaning | BILLING # | 2024 3rd Cleaning | 2024 4th Cleaning | 2023 | 2023 | 2023 | CLEANING | CLEANING | CLEANING | 2023 WAS number - 1 | Contractor - 1 | Cost - 1 | 2023 WAS number - 2 | Contractor - 2 | Cost - 2 | 2023 WAS number - 3 | Contractor - 3 | Cost - 3 | 2024 WAS number - 1 | Contractor - | Cost - 1 | 2024 WAS number - 2 | Contractor - 2 | Cost - 2 | 2023 WAS number - 3 | Contractor - 3 | Cost - 3 | REMARKS
Downtown | XUGS Macasandig | Daigler Wing | 3 | GF | Guidance Office | #1 | WRAC | 1.0HP | Conventional |  | WCARP010EA |  |  |  |  | 2021-01-22 |  |  |  |  |  |  |  |  |  |  |  |  |  | 2021-01-22
Downtown | XUGS Macasandig | Daigler Wing | 3 | GF | Guidance Office | #2 | WRAC | 1.0HP | Conventional |  | WCARP010EA/031415 |  |  |  | 2020-01-22 |  |  |  |  |  |  |  |  |  |  |  |  |  |  | 2020-01-22
Downtown | XUGS Macasandig | Daigler Wing | 3 | GF | Guidance Office | #3 | WRAC | 1.0HP | Conventional |  | WCARP010EA |  |  |  | 2020-01-22 |  |  |  |  |  |  |  |  |  |  |  |  |  |  | 2020-01-22
Downtown | XUGS Macasandig | Daigler Wing | 3 | GF | Guidance Office | #4 | WRAC | 1.5HP | Conventional |  | SERIAL NO. 0077674 |  |  |  | 2020-01-22 |  |  |  |  |  |  |  |  |  |  |  |  |  |  | 2020-01-22
Downtown | XUGS Macasandig | Daigler Wing | 3 | GF | Assistant Principal Admin 107 | #2 | WRAC | 2.5HP | Conventional |  | WCARH024EA - 0039152 |  |  |  | 2020-11-08 |  |  |  |  |  |  |  |  |  |  |  |  |  |  | 2020-11-08
Downtown | XUGS Macasandig | Daigler Wing | 3 | GF | Principal Secretary office | #1 | WM | 2.5HP |  |  | 42CVUR022-703 |  |  |  |  | 2021-01-22 |  |  |  |  |  |  |  |  |  |  |  |  |  | 2021-01-22
Downtown | XUGS Macasandig | Daigler Wing | 3 | GF | Principal Office | #1 | WRAC | 2.0HP | Conventional |  |  |  |  | 2019-12-10 |  |  |  |  |  |  |  |  |  |  |  |  |  |  |  | 2019-12-10
Downtown | XUGS Macasandig | Daigler Wing | 3 | GF | PASCU Room | #1 | CM | 3.0TR |  |  |  |  |  | 2019-12-10 |  |  |  |  |  |  |  |  |  |  |  |  |  |  |  | 2019-12-10
Downtown | XUGS Macasandig | Daigler Wing | 3 | GF | Reading language faculty Work room | #1 | WRAC | 2.0HP | Conventional |  |  |  |  | 2019-08-31 |  |  |  |  |  |  |  |  |  |  |  |  |  |  | 2019-08-31
Downtown | XUGS Macasandig | Daigler Wing | 3 | GF | Reading language faculty Work room | #2 | WRAC | 2.0HP | Conventional |  |  |  |  | 2019-08-31 |  |  |  |  |  |  |  |  |  |  |  |  |  |  | 2019-08-31
Downtown | XUGS Macasandig | Daigler Wing | 3 | GF | PTA Office Room 104 | #1 | WRAC | 1.5HP | Conventional |  | Inverter |  |  | 2019-12-10 |  |  |  |  |  |  |  |  |  |  |  |  |  |  |  | 2019-12-10
Downtown | XUGS Macasandig | Daigler Wing | 3 | GF | Perfect Office 118 | #1 | WRAC | 2.0HP | Conventional |  | APMRM180BA - For GC |  |  |  |  | 2021-01-20 |  |  |  |  |  |  |  |  |  |  |  |  |  | 2021-01-20
Downtown | XUGS Macasandig | Daigler Wing | 3 | GF | DAIGLER 103 principal off. | #1 | WRAC | 1.5HP | Conventional |  |  |  |  | 2019-12-10 |  |  |  |  |  |  |  |  |  |  |  |  |  |  |  | 2019-12-10
Downtown | XUGS Macasandig | Daigler Wing | 3 | GF | Daigler 116 Pre school coordinator | #1 | WRAC |  | Conventional |  |  |  |  | 2019-12-10 |  |  |  |  |  |  |  |  |  |  |  |  |  |  |  | 2019-12-10
Downtown | XUGS Macasandig | Daigler Wing | 3 | GF | Clinic/ ma'am hiede office 117 | #1 | WM | 1.0HP |  |  |  |  |  |  |  |  |  |  |  |  | 2024-07-10
Downtown | XUGS Macasandig | Daigler Wing | 3 | GF | Clinic/ ma'am hiede office 117 | #2 | WM | 1.0HP |  |  |  |  |  |  |  |  |  |  |  |  | 2024-07-10 |  |  |  |  |  |  |  |  |  |  |  |  |  |  |  |  |  |  |  |  |  |  |  |  |  |  |  |  | 24/APR/23-INSTALL BY CEA
Downtown | XUGS Macasandig | Daigler Wing | 3 | GF | Registrar | #1 | WRAC | 2.0HP | Conventional |  |  |  |  |  |  | 2021-01-20 |  |  |  |  |  |  |  |  |  |  |  |  |  | 2021-01-20
Downtown | XUGS Macasandig | Daigler Wing | 3 | GF | Registrar | #2 | WRAC | 2.5HP | Conventional |  |  |  |  |  | 2020-10-01 |  |  |  |  |  |  |  |  |  |  |  |  |  |  | 2020-10-01
Downtown | XUGS Macasandig | Daigler Wing | 3 | GF | ROOM 112 | #1 | FM | 3TR |  |  |  |  |  |  |  |  |  |  |  |  |  |  |  |  |  |  |  |  |  |  |  | 2023-09-20-23 | CEA | 3800.00 |  |  |  |  |  |  |  |  |  |  |  |  |  |  |  | 27/OCT/23-REPLACEMENT NEW INDOOR PCB BY CEA
Downtown | XUGS Macasandig | Daigler Wing | 3 | 2F | AVR office | #1 | WRAC | 1.0HP | Conventional | National - GC |  |  |  | 2019-12-12 |  |  |  |  |  |  |  |  |  |  |  |  |  |  |  | 2019-12-12
Downtown | XUGS Macasandig | Daigler Wing | 3 | 2F | AVR 1 Room 205 | #1 | WRAC | 2.0HP | Conventional |  | APMRM180BA - For GC |  |  | 2019-12-12 |  |  |  |  |  |  |  |  |  |  |  |  |  |  |  | 2019-12-12
Downtown | XUGS Macasandig | Daigler Wing | 3 | 2F | AVR 1 Room 205 | #2 | WRAC | 2.0HP | Conventional |  | CQSRM180BA (046405302) - For GC |  |  | 2019-12-12 |  |  |  |  |  |  |  |  |  |  |  |  |  |  |  | 2019-12-12
Downtown | XUGS Macasandig | Daigler Wing | 3 | 2F | AVR 2 | #1 | WRAC | 2.0HP | Conventional | Condura | 51QSXRACCONR19KEAMC |  |  | 2019-12-12 |  |  |  |  |  |  |  |  |  |  |  |  |  |  |  | 2019-12-12
Downtown | XUGS Macasandig | Daigler Wing | 3 | 2F | AVR 2 | #2 | WRAC | 2.5HP | Conventional | Condura |  |  |  | 2019-12-12 |  |  |  |  |  |  |  |  |  |  |  |  |  |  |  | 2019-12-12
Downtown | XUGS Macasandig | Daigler Wing | 3 | 2F | Library 1 | #1 | WRAC | 2.0HP | Conventional | Carrier |  |  |  |  |  | 2021-01-22 |  |  |  |  |  |  |  |  |  |  |  |  |  | 2021-01-22
Downtown | XUGS Macasandig | Daigler Wing | 3 | 2F | Library 2 | #2 | WRAC | 2.5HP | Conventional | Carrier |  |  |  |  |  | 2021-01-22 |  |  |  |  |  |  |  |  |  |  |  |  |  | 2021-01-22
Downtown | XUGS Macasandig | Daigler Wing | 3 | 2F | Library 3 | #3 | WRAC | 2.5HP | Conventional | Carrier |  |  |  | 2019-12-12 |  |  |  |  |  |  |  |  |  |  |  |  |  |  |  | 2019-12-12
Downtown | XUGS Macasandig | Daigler Wing | 3 | 2F | Library 4 | #4 | WRAC | 2.5HP | Conventional | Carrier |  |  |  |  | 2020-08-12 |  |  |  |  |  |  |  |  |  |  |  |  |  | 2020-08-12
Downtown | XUGS Macasandig | Daigler Wing | 3 | 2F | Library 5 | #5 | WRAC | 2.5HP | Conventional | Carrier |  |  |  | 2019-12-12 |  |  |  |  |  |  |  |  |  |  |  |  |  |  |  | 2019-12-12
Downtown | XUGS Macasandig | Daigler Wing | 3 | 2F | Library 6 | #6 | WRAC | 2.5HP | Conventional | Carrier |  |  |  | 2019-12-12 |  |  |  |  |  |  |  |  |  |  |  |  |  |  |  | 2019-12-12
Downtown | XUGS Macasandig | Daigler Wing | 3 | 2F | Library(Faculty and Staff Area | #7 | WRAC | 2.5HP | Conventional | Carrier |  |  |  | 2019-12-12 |  |  |  |  |  |  |  |  |  |  |  |  |  |  |  | 2019-12-12
Downtown | XUGS Macasandig | Daigler Wing | 3 | 2F | Library (Preschool learning) | #1 | WRAC | 2.5HP | Conventional |  |  |  |  | 2019-12-12 |  |  |  |  |  |  |  |  |  |  |  |  |  |  |  | 2019-12-12
Downtown | XUGS Macasandig | Daigler Wing | 3 | 2F | Library (Preschool learning) | #2 | WRAC | 1.0HP | Conventional |  |  |  |  | 2019-12-12 |  |  |  |  |  |  |  |  |  |  |  |  |  |  |  | 2019-12-12
Downtown | XUGS Macasandig | Daigler Wing | 3 | 2F | Librarian's Office | #1 | WM | 1.0HP |  | Carrier Alpha |  |  |  | 2019-12-13 |  |  |  |  |  |  |  |  |  |  |  |  |  |  |  | 2019-12-13
Downtown | XUGS Macasandig | Daigler Wing | 3 | 2F | SRA Lab 204 | #1 | WM | 3.0HP |  |  |  |  |  | 2019-12-13 |  |  |  |  |  |  |  |  |  |  |  |  |  |  |  | 2019-12-13
Downtown | XUGS Macasandig | Daigler Wing | 3 | 2F | Makabayan Mapeh Faculty Room 211 | #1 | WRAC | 2.0HP | Conventional |  |  |  |  |  | 2020-10-02 |  |  |  |  |  |  |  |  |  |  |  |  |  |  | 2020-10-02
Downtown | XUGS Macasandig | Daigler Wing | 3 | 2F | Makabayan Mapeh Work Room 211 | #2 | WRAC | 2.0HP | Conventional |  |  |  |  |  | 2020-09-02 |  |  |  |  |  |  |  |  |  |  |  |  |  | 2020-09-02
Downtown | XUGS Macasandig | Daigler Wing | 3 | 3F | Auditorium asset.163836 | #1 | FM | 7.5TR | Conventional | CARRIER | M#-38HDS007P | Operational |  | 2019-12-13 |  |  |  |  |  |  | 2024-06-25 |  |  |  |  |  |  |  |  | 2019-12-13 |  | 2023-09-20-23 | CEA | 9500.00 |  |  |  |  |  |  |  |  |  |  |  |  |  |  |  | 24/OCT/23-LEAK REPSIR&REPLACE MAGNETIC CONTACTOR BY CEA
Downtown | XUGS Macasandig | Daigler Wing | 3 | 3F | Auditorium asset.163839 | #2 | FM | 7.5TR |  |  |  | Operational |  |  |  |  |  |  |  |  | 2024-06-25 |  |  |  |  |  | 2023-10-04 |  |  | 2023-10-04
Downtown | XUGS Macasandig | Daigler Wing | 3 | 3F | Auditorium asset.163834 | #3 | FM | 7.5TR |  | CARRIER |  | Operational |  |  |  |  |  |  |  |  | 2024-06-25 |  |  |  |  |  | 2023-10-04 |  |  | 2023-10-04 |  | 2023-09-20-23 | CEA | 9500.00 |  |  |  |  |  |  |  |  |  |  |  |  |  |  |  | 24/OCT/23-LEAK TEST&REPLACE MAGNETIC CONTACTOR BY CEA
Downtown | XUGS Macasandig | Daigler Wing | 3 | 3F | Auditorium asset.163835 | #4 | FM | 7.5TR |  |  |  | Operational |  |  |  |  |  |  |  |  | 2024-06-25 |  |  |  |  |  | 2023-10-04 |  |  | 2023-10-04
Downtown | XUGS Macasandig | Daigler Wing | 3 | 3F | Auditorium asset.163838 | #5 | FM | 7.5TR |  |  |  | Operational |  |  |  |  |  |  |  |  | 2024-06-25 |  |  |  |  |  | 2023-10-04 |  |  | 2023-10-04
Downtown | XUGS Macasandig | Daigler Wing | 3 | 3F | Auditorium asset.163837 | #6 | FM | 7.5TR |  |  |  | Operational |  |  |  |  |  |  |  |  | 2024-06-25 |  |  |  |  |  | 2023-10-04 |  |  | 2023-10-04
Downtown | XUGS Macasandig | Daigler Wing | 3 | 3F | ROOM 306 | #1 | FM | 3TR |  |  |  | Operational |  |  |  |  |  |  |  |  | 2024-07-10 |  |  |  |  |  | 2023-10-04 |  |  | 2023-10-04
Downtown | XUGS Macasandig | Daigler Wing | 3 | 3F | ROOM 306 | #2 | WRAC | 1HP | Conventional |  |  | Operational |  |  |  |  |  |  |  |  | 2024-07-10 |  |  |  |  |  | 2023-10-04 |  |  | 2023-10-04
Downtown | XUGS Macasandig | Daigler Wing | 3 | 3F | ROOM 306 | #3 | WRAC | 2HP | Conventional |  |  | Operational |  |  |  |  |  |  |  |  | 2024-07-10 |  |  |  |  |  | 2023-10-04 |  |  | 2023-10-04
Downtown | XUGS Macasandig | Daigler Wing | 3 | 3F | ROOM 306 | #4 | FM | 3TR |  |  |  | Operational |  |  |  |  |  |  |  |  | 2024-07-10 |  |  |  |  |  | 2023-10-04 |  |  | 2023-10-04
Downtown | XUGS Macasandig | Daigler Wing | 3 | 3F | ROOM 309 |  | CM | 5. 0TR |  |  |  |  |  |  |  |  |  |  |  |  | 2024-06-25
Downtown | XUGS Macasandig | Daigler Wing | 3 | 3F | ROOM 309 |  | CM | 5.0TR |  |  |  |  |  |  |  |  |  |  |  |  | 2024-06-25
Downtown | XUGS Macasandig | OTHER BLDG | G | GF | Chapel BLDG. Chaplain office | #1 | WRAC |  | Conventional |  |  |  |  | 2019-10-15 |  |  |  |  |  |  | 2024-07-10 |  |  |  |  |  |  |  |  | 2019-10-15
Downtown | XUGS Macasandig | OTHER BLDG | G | GF | Chapel Bldg. | #1 | WRAC |  | Conventional | Carrier |  |  |  | 2019-12-19 |  |  |  |  |  |  | 2024-07-10 |  |  |  |  |  |  |  |  | 2019-12-19
Downtown | XUGS Macasandig | OTHER BLDG | G | GF | Chapel Bldg. | #2 | WRAC |  | Conventional | Carrier |  |  |  | 2019-12-19 |  |  |  |  |  |  | 2024-07-10 |  |  |  |  |  |  |  |  | 2019-12-19
Downtown | XUGS Macasandig | OTHER BLDG | G | GF | Chapel Bldg. | #3 | WRAC |  | Conventional | Carrier |  |  |  |  |  |  |  |  |  |  | 2024-07-10 |  |  |  |  |  |  |  |  | 2029-12-19
Downtown | XUGS Macasandig | OTHER BLDG | G | GF | Chapel Bldg. CM Office | #4 | WRAC |  | Conventional | Carrier |  |  |  |  | 2020-08-11 |  |  |  |  |  | 2024-07-10 |  |  |  |  |  |  |  | 2020-08-11
Downtown | XUGS Macasandig | OTHER BLDG | G | GF | Book Center wcargo919ea-027138 | #1 | WRAC | 2.0HP | Conventional |  | WCARG0919EA - 0297138 |  |  |  |  |  |  |  |  |  |  |  |  |  |  |  |  |  | 2002-08-11
Downtown | XUGS Macasandig | OTHER BLDG | G | GF | RISO Room apxrm195ba-031525811 | #1 | WRAC | 2.0HP | Conventional |  | APXRM195BA - 031525811 |  |  |  |  |  |  |  |  |  | 2024-07-10 |  |  |  |  |  |  |  |  | 2029-12-19
Downtown | XUGS Macasandig | OTHER BLDG | G | GF | Athletics and Sports Office | #1 | WRAC | 2.0HP | Conventional |  |  |  |  | 2019-08-30 |  |  |  |  |  |  |  |  |  |  |  |  |  |  | 2019-08-30
Downtown | XUGS Macasandig | OTHER BLDG | G | GF | Speech Lab | #1 | WRAC | 2.0HP | Conventional |  |  |  |  |  |  |  |  |  |  |  |  |  |  |  |  |  |  |  |  |  |  |  |  |  |  |  |  |  |  |  |  |  |  |  |  |  |  |  |  | NOT IN USE
Downtown | XUGS Macasandig | OTHER BLDG | G | GF | Speech Lab | #2 | WRAC | 2.0HP | Conventional |  |  |  |  |  |  |  |  |  |  |  |  |  |  |  |  |  |  |  |  |  |  |  |  |  |  |  |  |  |  |  |  |  |  |  |  |  |  |  |  | NOT IN USE
Downtown | XUGS Macasandig | OTHER BLDG | G | GF | Math Science work room |  | WRAC | 1.0HP | Conventional |  | SERIAL NO.0433509 |  |  |  | 2020-09-02 |  |  |  |  |  |  |  |  |  |  |  |  |  | 2020-09-02
Downtown | XUGS Macasandig | OTHER BLDG | G | GF | PPO Office |  | WRAC | 1.5HP | Conventional |  |  |  |  | 2019-09-17 |  |  |  |  |  |  |  |  |  |  |  |  |  |  | 2019-09-17
Downtown | XUGS Macasandig | HAYES WING | 2 | GF | Computer Lab A | #1 | WRAC | 2.0HP | Conventional |  | APMRM180BA |  |  |  |  | 2021-01-20 |  |  |  |  | 2024-06-25 |  |  |  |  |  |  |  |  | 2021-01-20
Downtown | XUGS Macasandig | HAYES WING | 2 | GF | Computer Lab A | #2 | WM | 2.0HP |  |  | 42CVUR016-703 |  |  |  |  | 2021-01-23 |  |  |  |  | 2024-06-25 |  |  |  |  |  |  |  |  | 2021-01-23
Downtown | XUGS Macasandig | HAYES WING | 2 | GF | Computer Lab A | #1 | WRAC | 2.0HP | Conventional |  | APXRM195BA |  |  |  | 2020-09-02 |  |  |  |  |  | 2024-06-25 |  |  |  |  |  |  |  | 2020-09-02
Downtown | XUGS Macasandig | HAYES WING | 2 | GF | Computer Lab B | #1 | WRAC | 2.5HP | Conventional |  | WCARG024EA |  |  | 2019-08-31 |  |  |  |  |  |  | 2024-06-25 |  |  |  |  |  |  |  | 2019-08-31
Downtown | XUGS Macasandig | HAYES WING | 2 | GF | Computer Lab B | #2 | WRAC | 2.5HP | Conventional |  | 51PMXRRACCAP24KEAP3C |  |  | 2019-08-31 |  |  |  |  |  |  | 2024-06-25 |  |  |  |  |  |  |  | 2019-08-31
Downtown | XUGS Macasandig | HAYES WING | 2 | GF | AP Academic Office | #1 | WM | 1.0HP |  |  |  |  |  |  |  | 2021-01-20 |  |  |  |  |  |  |  |  |  |  |  |  |  | 2021-01-20
Downtown | XUGS Macasandig | HAYES WING | 2 | GF | AP Academic Office | #2 | WRAC | 2.0HP | Conventional |  |  |  |  |  |  | 2021-01-23 |  |  |  |  |  |  |  |  |  |  |  |  |  | 2021-01-23
Downtown | XUGS Macasandig | HAYES WING | 2 | GF | ROOM 102 | #1 | CM | 3.0TR |  |  | 163793 |  |  |  |  |  |  |  |  |  | 2024-07-10
Downtown | XUGS Macasandig | HAYES WING | 2 | GF | ROOM 102 | #2 | CM | 3.0TR |  |  |  |  |  |  |  |  |  |  |  |  | 2024-07-10
Downtown | XUGS Macasandig | CERVINI WING | 2 | GF | Room 104 | #1 | WRAC | 2.5HP |  |  | WCARPO19EA | Operational |  |  |  |  |  |  |  |  | 2024-07-10 |  |  |  |  |  | 2023-10-04 |  |  | 2023-10-04
Downtown | XUGS Macasandig | CERVINI WING | 2 | GF | ROOM 104 | #2 | WRAC | 1.0HP | Conventional |  | 142898 ASST | Operational |  |  |  |  |  |  |  |  | 2024-07-10 |  |  |  |  |  | 2023-10-04 |  |  | 2023-10-04
Downtown | XUGS Macasandig | CERVINI WING | 2 | GF | Room 109 | #1 | WM | 1.0HP | Conventional |  | 142900 |  |  | 2019-09-14 |  |  |  |  |  |  | 2024-07-10 |  |  |  |  |  |  |  | 2019-09-14
Downtown | XUGS Macasandig | CERVINI WING | 2 | GF |  |  |  |  | Conventional
Downtown | XUGS Macasandig | CERVINI WING | 2 | 2F | ROOM 203 | #1 | WRAC | 2.5HP |  |  |  | Operational |  |  |  |  |  |  |  |  | 2024-07-10
Downtown | XUGS Macasandig | CERVINI WING | 2 | 2F | ROOM 204 | #1 | WRAC | 2.5HP |  |  |  | Operational |  |  |  |  |  |  |  |  | 2024-07-10
Downtown | XUGS Macasandig | CERVINI WING | 2 | 2F | ROOM 204 | #2 | WRAC | 1.0HP |  |  |  | Operational |  |  |  |  |  |  |  |  | 2024-07-10
Downtown | XUGS Macasandig | CERVINI WING | 2 | 2F | ROOM 206 | #1 | WRAC | 1.5HP |  |  |  | Operational |  |  |  |  |  |  |  |  | 2024-07-10
Downtown | XUGS Macasandig | CERVINI WING | 2 | 2F | ROOM 207 | #1 | WRAC | 2HP |  |  |  | Operational |  |  |  |  |  |  |  |  | 2024-07-10
Downtown | XUGS Macasandig | CERVINI WING | 2 | 2F | ROOM 209 | #1 | WRAC | 2.0HP | Conventional |  | WCARP019EA | Operational |  |  |  |  |  |  |  |  | 2024-07-10 |  |  |  |  |  |  |  |  | 2016-01-26
Downtown | XUGS Macasandig | CERVINI WING | 2 | 2F | ROOM 210 | #2 | WRAC | 2.5HP | Conventional |  | WCARPO24EA | Operational |  |  |  |  |  |  |  |  | 2024-07-10 |  |  |  |  |  |  |  |  | 2016-01-26
Downtown | XUGS Macasandig | CERVINI WING | 2 | 2F | ROOM 210 | #1 | WRAC | 2.0HP |  |  |  | Operational |  |  |  |  |  |  |  |  | 2024-07-10
Downtown | XUGS Macasandig | CERVINI WING | 2 | 2F | Room 211 | #1 | WRAC | 2.0HP |  |  | WCARP019EA | Operational |  |  |  |  |  |  |  |  | 2024-07-10
Downtown | XUGS Macasandig | CERVINI WING | 2 | 2F | Room 211 | #2 | WRAC | 2.0HP |  |  | WCARP019EA | Operational |  |  |  |  |  |  |  |  | 2024-07-10
Downtown | XUGS Macasandig | CERVINI WING | 2 | 2F |  |  |  |  | Conventional |  | APMRM195BA |  |  |  |  |  |  |  |  |  |  |  |  |  |  |  |  |  |  | 2016-01-26
Downtown | XUGS Macasandig | CERVINI WING | 2 | 2F |  |  |  |  | Conventional |  | WCARG014EA |  |  |  |  |  |  |  |  |  |  |  |  |  |  |  |  |  |  | 2016-01-26
Downtown | XUGS Macasandig | CERVINI WING | 2 | 3F | Room 311 | #1 | WRAC | 2.0HP | Conventional |  |  | Operational |  |  |  |  |  |  |  |  | 2024-07-10
Downtown | XUGS Macasandig | CERVINI WING | 2 | 3F | Room 311 | #2 | WRAC | 2.0HP |  |  |  | Operational |  |  |  |  |  |  |  |  | 2024-07-10
Downtown | XUGS Macasandig | CERVINI WING | 2 | 3F | ROOM 310 | #2 | WRAC | 1.5HP |  |  |  | Operational |  |  |  |  |  |  |  |  | 2024-07-10
Downtown | XUGS Macasandig | CERVINI WING | 3 | 3F | V-SCH.FERNANDO ROOM 309 | #1 | WM | 1.0HP |  | CARRIER |  | Operational |  |  |  |  |  |  |  |  | 2024-07-10 |  |  |  |  | 2023-08-23 |  |  | 2023-08-23 |  |  |  |  |  |  |  |  |  |  |  |  |  |  |  |  |  |  |  |  | 23/AUG/23=INSTALLED BY GARY
Downtown | XUGS Macasandig | CERVINI WING | 3 | 3F | V-SCH.FERNANDO ROOM 309 | #2 | WM | 1.0HP |  | CARRIER |  | Operational |  |  |  |  |  |  |  |  | 2024-07-10 |  |  |  |  | 2023-08-23 |  |  | 2023-08-23 |  |  |  |  |  |  |  |  |  |  |  |  |  |  |  |  |  |  |  |  | 23/AUG/23=INSTALLED BY GARY
Downtown | XUGS Macasandig | CERVINI WING | 3 | 3F | V-POPE FRANCIS ROOM 308 | #1 | WM | 1.0HP |  | CARRIER |  | Operational |  |  |  |  |  |  |  |  | 2024-07-10
Downtown | XUGS Macasandig | CERVINI WING | 3 | 3F | V-POPE FRANCIS ROOM 308 | #2 | WM | 1.0HP |  | CARRIER |  | Operational |  |  |  |  |  |  |  |  | 2024-07-10
Downtown | XUGS Macasandig | CERVINI WING | 3 | 3F | IV-BL PRO ROOM 307 | #1 | WM | 1.0HP |  | CARRIER |  | Operational |  |  |  |  |  |  |  |  | 2024-07-10
Downtown | XUGS Macasandig | CERVINI WING | 3 | 3F | IV-BL PRO ROOM 307 | #2 | WM | 1.0HP |  | CARRIER |  | Operational |  |  |  |  |  |  |  |  | 2024-07-10
Downtown | XUGS Macasandig | CERVINI WING | 3 | 3F | ROOM 304 | #1 | WM | 1.0HP |  | CARRIER |  | Operational |  |  |  |  |  |  |  |  | 2024-07-10
Downtown | XUGS Macasandig | CERVINI WING | 3 | 3F | ROOM 304 | #2 | WM | 1.0HP |  | CARRIER |  | Operational |  |  |  |  |  |  |  |  | 2024-07-10
Downtown | XUGS Macasandig | CERVINI WING | 3 | 3F | IV-ST,MIKI ROOM 303 | #1 | WM | 1.0HP |  | CARRIER |  | Operational |  |  |  |  |  |  |  |  | 2024-07-10
Downtown | XUGS Macasandig | CERVINI WING | 3 | 3F | IV-ST,MIKI ROOM 303 | #2 | WM | 1.0HP |  | CARRIER |  | Operational |  |  |  |  |  |  |  |  | 2024-07-10
Downtown | XUGS Macasandig | CERVINI WING | 3 | 3F | IV-ST,ARROWSMITH 302 | #1 | WM | 1.0HP |  | CARRIER |  | Operational |  |  |  |  |  |  |  |  | 2024-07-10
Downtown | XUGS Macasandig | CERVINI WING | 3 | 3F | IV-ST,ARROWSMITH 302 | #2 | WM | 1.0HP |  | CARRIER |  | Operational |  |  |  |  |  |  |  |  | 2024-07-10
Uptown | XU ALGCIT | MERCEDES | 3 | GF | COMPUTER LAB | #1 | WRAC | 2.0HP | Conventional | CARRIER |  | Operational |  |  |  |  |  |  |  |  | 2024-08-15
Uptown | XU ALGCIT | MERCEDES | 3 | GF | COMPUTER LAB | #2 | WRAC | 2.0HP | Conventional | CARRIER |  | Operational |  |  |  |  |  |  |  |  | 2024-08-15
Uptown | XU ALGCIT | MERCEDES | 3 | GF | COMPUTER LAB | #3 | WRAC | 2.0HP | Conventional | CARRIER |  | Operational |  |  |  |  |  |  |  |  | 2024-08-15
Uptown | XU ALGCIT | MERCEDES | 3 | GF | CLINIC | #1 | WM | 1.5HP | Inverter | CARRIER | 42CVES016/72200232 | Operational |  |  |  |  |  |  |  |  | 2024-08-15
Uptown | XU ALGCIT | MERCEDES | 3 | GF | CLINIC | #2 | WM | 1.0HP | Inverter | CARRIER | 42CVES010/7310257 | Operational |  |  |  |  |  |  |  |  | 2024-08-15
Uptown | XU ALGCIT | MERCEDES | 3 | GF | CLINIC | #3 | WM | 1.0HP | Inverter | CARRIER | 42CVES010 | Operational |  |  |  |  |  |  |  |  | 2024-08-15
Uptown | XU ALGCIT | MERCEDES | 3 | GF | CLINIC | #4 | WM | 1.0HP | Inverter | CARRIER | 42CVES010/72800389 | Operational |  |  |  |  |  |  |  |  | 2024-08-15
Uptown | XU ALGCIT | MERCEDES | 3 | GF | CLINIC | #5 | WM | 1.0HP | Inverter | CARRIER | 42CVES010/72600229 | Operational |  |  |  |  |  |  |  |  | 2024-08-15
Uptown | XU ALGCIT | MERCEDES | 3 | GF | CLINIC | #6 | WM | 1.0HP | Inverter | CARRIER | 42CVES010/73102590 | Operational |  |  |  |  |  |  |  |  | 2024-08-15
Uptown | XU ALGCIT | MERCEDES | 3 | GF | PRINCIPAL /APS / GUIDANCE | #1 | WM | 1.0HP | Inverter | CARRIER | S-72900042 | Operational |  |  |  |  |  |  |  |  | 2024-08-15
Uptown | XU ALGCIT | MERCEDES | 3 | GF | PRINCIPAL /APS / GUIDANCE | #2 | WM | 1.0HP | Inverter | CARRIER | S-72900042 | Operational |  |  |  |  |  |  |  |  | 2024-08-15
Uptown | XU ALGCIT | MERCEDES | 3 | 2F | GRADE 5 FACULTY ROOM | #1 | WM | 1.5HP | Inverter | CARRIER |  | Operational |  |  |  |  |  |  |  |  | 2024-08-15
Uptown | XU ALGCIT | MERCEDES | 3 | 2F | GRADE 5 FACULTY ROOM | #2 | WM | 1.0HP | Inverter | CARRIER |  | Operational |  |  |  |  |  |  |  |  | 2024-08-15
Uptown | XU ALGCIT | MERCEDES | 3 | 3F | GRADE 6 FACULTY ROOM | #1 | WM | 1.5HP | Inverter | CARRIER |  | Operational |  |  |  |  |  |  |  |  | 2024-08-15
Uptown | XU ALGCIT | MERCEDES | 3 | 3F | GRADE 6 FACULTY ROOM | #2 | WM | 1.0HP | Inverter | CARRIER |  | Operational |  |  |  |  |  |  |  |  | 2024-08-15
Uptown | XU Pueblo | Grade School | 3 | GF | ASSISTANT PRINCIPAL | #1/0315345 | WRAC | 2.0HP | Conventional |  |  | Operational |  |  |  |  | 2022-10-14 |  |  |  | 2024-01-10 | 2024-05-02 |  |  |  | 2023-08-03 |  |  | 2023-08-03 | 2022-10-14
Uptown | XU Pueblo | Grade School | 3 | GF | PRINCIPALS OFFICE | #1/62400509 | WM | 1.5HP | Inverter |  |  | Operational |  |  |  |  |  | 2023-08-03 |  |  | 2024-01-10 | 2024-09-24 | GS2409-081 |  |  | 2023-08-03 |  | 2023-02-23 | 2023-08-03 |  | 2023-02-23
Uptown | XU Pueblo | Grade School | 3 | GF | PRINCIPALS OFFICE | #2/92550072 | WM | 1.0HP | Inverter |  |  | Operational |  |  |  | 2021-10-25 |  |  |  |  | 2024-01-10 | 2024-09-24 | GS2409-081 |  |  |  |  |  |  | 2021-10-25
Uptown | XU Pueblo | Grade School | 3 | GF | CLINIC | #1/30170019 | WM | 3.0HP | Inverter |  |  | Operational |  |  |  |  | 2022-10-21 |  |  |  | 2024-01-10 | 2024-05-02 | GS2409-081 | 2024-09-24 |  | 2023-08-03 |  |  | 2023-08-03 | 2022-10-21
Uptown | XU Pueblo | Grade School | 3 | GF | CLINIC | #2/060170047 | WM | 3.0HP | Inverter |  |  | Operational |  |  |  |  | 2022-10-21 |  |  |  | 2024-01-10 | 2024-05-02 | GS2409-081 | 2024-09-24 |  | 2023-08-03 |  |  | 2023-08-03 | 2022-10-21
Uptown | XU Pueblo | Grade School | 3 | GF | CONFERENCE ROOM | #1 | WM | 1.5HP | Inverter |  | 800207 | Operational |  |  |  |  | 2022-10-14 |  | 2023-12-06 |  | 2024-05-02 | 2024-09-24 | GS2409-081 |  |  | 2023-08-03 |  |  | 2023-08-03 | 2022-10-14
Uptown | XU Pueblo | Grade School | 3 | GF | GUIDANCE OFFICEN RECEIVING | #1/42100107 | WM | 3.0HP | Inverter |  |  | Operational |  |  |  |  |  |  |  |  | 2024-01-10 | 2024-05-02 | GS2409-081 | 2024-09-24
Uptown | XU Pueblo | Grade School | 3 | GF | GUIDANCE OFFICE | #2/C0392704 | WRAC | 1.0HP | Conventional |  | 92500434 | Operational |  |  |  |  | 2022-10-14 |  | 2023-12-06 |  | 2024-01-10 | 2024-05-02 | GS2409-081 | 2024-09-24 |  | 2023-08-03 |  |  | 2023-08-03 | 2022-10-14
Uptown | XU Pueblo | Grade School | 3 | GF | GUIDANCE OFFICE | #3 | WRAC | 1.0HP | Conventional |  |  | Operational |  |  |  |  | 2022-10-14 |  |  |  | 2024-01-10 | 2024-05-02 | GS2409-081 | 2024-09-24 |  | 2023-08-19 |  |  | 2023-08-19 | 2022-10-14
Uptown | XU Pueblo | Grade School | 3 | GF | GUIDANCE OFFICE | #4/909845 | WRAC | 1.0HP | Conventional |  |  | Operational |  |  |  |  |  | 2023-08-19 |  |  | 2024-01-10 | 2024-05-02 | GS2409-081 | 2024-09-24 |  | 2023-08-19 |  | 2023-02-28 | 2023-08-19 |  | 2023-02-28
Uptown | XU Pueblo | Grade School | 3 | GF | ADC / ACADEMIC | #1 | CM | 3.0TR | Conventional |  | 200848 | Operational |  |  |  |  | 2022-10-14 |  | 2023-12-06 |  | 2024-05-02 |  |  |  |  | 2023-08-03 |  |  | 2023-08-03 | 2022-10-14 |  |  |  |  |  |  |  |  |  |  |  |  |  |  |  |  |  |  |  | JUL/17/2023=DISMANTLED BY CEA
Uptown | XU Pueblo | Grade School | 3 | GF | AP FORMATION | #1 | WM | 3.0HP | Inverter |  | 2800217 | Operational |  |  |  |  | 2022-10-14 |  | 2023-12-06 |  | 2024-05-02 | 2024-09-24 | GS2409-081 |  |  | 2023-08-03 |  |  | 2023-08-03 | 2022-10-14 |  |  |  |  |  |  |  |  |  |  |  |  |  |  |  |  |  |  |  | JUL/17/2023=DISMANTLED BY CEA
Uptown | XU Pueblo | Grade School | 3 | GF | AP FOR ACAD | #1 | WM | 1.5HP | Inverter |  |  | Operational |  |  |  |  |  |  |  |  | 2024-05-02 | 2024-09-24 | GS2409-081 |  |  |  |  | 2023-02-27 |  |  | 2023-02-27
Uptown | XU Pueblo | Grade School | 3 | GF | AP FOR ACAD | #2 | WM | 1.5HP | Inverter |  |  | Operational |  |  |  |  |  |  |  |  | 2024-05-02 | 2024-09-24 | GS2409-081 |  |  | 2023-08-03 |  |  | 2023-08-03
Uptown | XU Pueblo | Grade School | 3 | GF | CAMPUS MINISTRY OFFICE / CMO | #1 | WM | 1.5HP | Inverter |  |  | Operational |  |  |  |  | 2022-10-19 |  |  |  | 2024-05-02 | 2024-09-24 | GS2409-081 |  |  | 2023-08-19 |  |  | 2023-08-19 | 2022-10-19 |  |  |  |  |  |  |  |  |  |  |  |  |  |  |  |  |  |  |  | JUL/17/2023=DISMANTLED BY CEA
Uptown | XU Pueblo | Grade School | 3 | GF | CHAPEL | #1 | CM | 3.0TR | Conventional |  |  | Operational |  |  |  |  | 2022-10-19 |  | 2023-12-06 |  | 2024-05-02 | 2024-09-24 | GS2409-081 |  |  | 2023-08-19 |  |  | 2023-08-19 | 2022-10-19 |  |  |  |  |  |  |  |  |  |  |  |  |  |  |  |  |  |  |  | JUL/17/2023=DISMANTLED BY CEA
Uptown | XU Pueblo | Grade School | 3 | GF | CHAPEL | #2 | CM | 3.0TR | Conventional |  |  | Operational |  |  |  |  |  | 2023-08-03 |  |  | 2024-05-02 | 2024-09-24 | GS2409-081 |  |  | 2023-08-03 |  | 2023-02-27 | 2023-08-03 |  | 2023-02-27 |  |  |  |  |  |  |  |  |  |  |  |  |  |  |  |  |  |  | JUL/17/2023=DISMANTLED BY CEA
Uptown | XU Pueblo | Grade School | 3 | GF | REGISTRAR OFFICE | #1 | WM | 1.0HP | Inverter |  |  | Operational |  | 2019-09-23 |  |  |  |  |  |  | 2024-06-13 | 2024-09-24 | GS2409-081 |  |  |  |  |  | 2019-09-23
Uptown | XU Pueblo | Grade School | 3 | GF | PREFECT OF DISCIPLINE | #1/82800863 | WM | 1.0HP | Inverter |  |  | Operational |  | 2019-09-23 |  |  |  |  |  |  | 2024-05-02 | 2024-09-24 | GS2409-081 |  |  |  |  |  | 2019-09-23
Uptown | XU Pueblo | Grade School | 3 | 2F | LIBRARY | #1 | WM | 3.0HP | Conventional |  |  | With Concern |  |  |  |  |  | 2023-08-03 | 2023-12-06 |  | 2024-06-13 | 2024-09-24 | GS2409-081 |  |  | 2023-08-03 |  | 2023-02-23 | 2023-08-03 |  | 2023-02-23 |  |  |  |  |  |  |  |  |  | 2024-2-07-15 | GARY | 13930.00 |  |  |  |  |  |  | 13-MAR-23 LEAK REPAIR & REPLACEMENT OF OUTDOOR FAN MOTOR
Uptown | XU Pueblo | Grade School | 3 | 2F | LIBRARY | #2 | FM | 3.0TR | Conventional |  |  | With Concern |  |  |  |  |  | 2023-08-03 | 2023-12-06 |  | 2024-06-13 | 2024-09-24 | GS2409-081 |  |  | 2023-08-03 |  | 2023-02-23 | 2023-08-03 |  | 2023-02-23
Uptown | XU Pueblo | Grade School | 3 | 2F | LIBRARY | #3 | FM | 3.0TR | Conventional |  |  | Operational |  |  |  |  |  | 2023-08-03 | 2023-12-06 |  | 2024-06-13 | 2024-09-24 | GS2409-081 |  |  | 2023-08-03 |  | 2023-02-23 | 2023-08-03 |  | 2023-02-23 |  |  |  |  |  |  |  |  |  | 2024-03-05-11 | CEA | 9650.00 |  |  |  |  |  |  | 24-APR-24-OUTDOOR FAN MOTOR REPLACEMENT
Uptown | XU Pueblo | Grade School | 3 | 2F | LIBRARY | #4 | CM | 5.0TR | Conventional |  |  | Operational |  |  |  |  | 2022-10-17 |  |  |  | 2024-06-13 | 2024-09-24 | GS2409-081 |  |  | 2023-08-03 |  |  | 2023-08-03 | 2022-10-17
Uptown | XU Pueblo | Grade School | 3 | 2F | AVR | #1 | FM | 3.0TR | Conventional |  |  | Operational |  |  |  |  | 2022-10-17 |  |  |  | 2024-06-13 |  |  |  |  | 2023-08-03 |  |  | 2023-08-03 | 2022-10-17
Uptown | XU Pueblo | Grade School | 3 | 2F | AVR | #2 | FM | 3.0TR | Conventional |  |  | Operational |  |  |  |  |  |  |  |  | 2024-06-13
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

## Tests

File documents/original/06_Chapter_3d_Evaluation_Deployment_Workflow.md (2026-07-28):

# Chapter III (Part 4): Model Evaluation, Deployment & Workflow

## 3.4 Model Evaluation

### Confusion Matrix

All classification models are evaluated via confusion matrix:

| | Predicted Positive | Predicted Negative |
|---|---|---|
| **Actual Positive** | True Positive (TP) | False Negative (FN) — Type II error |
| **Actual Negative** | False Positive (FP) — Type I error | True Negative (TN) |

### Performance Metrics

#### Accuracy
```
Accuracy = (TP + TN) / (TP + TN + FP + FN)
```
Proportion of correct predictions. Valid for **balanced** datasets only — can be misleading when classes are imbalanced.

#### Precision
```
Precision = TP / (TP + FP)
```
Ratio of correctly predicted positives among all positive predictions. Used when **low false positive rate** is critical.

#### Recall (Sensitivity)
```
Recall = TP / (TP + FN)
```
Ratio of correctly predicted positives among all actual positives. Used when **low false negative rate** is critical.

**Trade-off:** High precision → poor recall, and vice versa.

#### F1 Score
```
F1 = 2 × (Precision × Recall) / (Precision + Recall)
```
Harmonic mean of precision and recall. Used when both need to be considered simultaneously.

### Statistical Analysis

After k-fold cross-validation during training, the test split is grouped into **30 subsets**, each cross-validated across n models. Each model is evaluated on accuracy, precision, recall, and F1.

Since dataset accuracy typically ranges 80–95% (non-normal distribution), the **Friedman Test** is used — a non-parametric alternative to Repeated Measures ANOVA.

**Hypotheses:**
- H₀: The means across all models are equal.
- H₁: At least one population mean differs from the rest.

---

## 3.5 Model Deployment

The final phase transitions the trained model from a static saved file (`.pkl` or `.pth`) into a functional decision-support system displaying real-time health status of monitored AC units.

**Context:** University research prototype — prioritizes pragmatic, achievable deployment without complex enterprise infrastructure.

### 8.1 Deployment Architecture & Technology

Hosted on the central **Ingest Server** (already receiving data from all 50 Master ESP32 nodes).

#### Streamlit (Application Framework)
- Open-source Python framework for interactive data-driven web apps.
- **No HTML/CSS/JavaScript required** — suited for a mechanical engineering student.
- Dashboard displays model predictions and sensor data.

#### SQLite (Prediction Database)
- Serverless, self-contained database built into Python (`sqlite3` module).
- Stores entire database in a single file.
- Ideal for a research prototype — no database server installation overhead.
- Stores prediction history for all units.

#### Watchdog (Automation)
- Python library that monitors directories for file system events.
- Detects new file creation in raw data folder.
- Triggers automated prediction pipeline.

### 8.2 Deployment Workflow

Two connected components:

#### Component 1: Automated Inference Service

A persistent Python script running on the Ingest Server:

1. **Monitor:** Watchdog watches `02_Data/raw/` directory.
2. **Trigger:** When a Master ESP32 saves a new file (e.g., `20251116T110400Z_SBM-AVR_ACU-01_T03_RAW.csv`), the "file created" event fires.
3. **Execute Prediction Pipeline:**
   - a. Load and preprocess the new CSV: apply CCFs from calibration database, run preprocessing scripts.
   - b. Load the best trained model (e.g., `random_forest_final.pkl`) via `joblib`/`pickle`.
   - c. Call `model.predict()` on processed data → "Normal" or "Abnormal".
4. **Store:** Insert prediction into `predictions.db` SQLite table with Unit ID, timestamp, and result.

#### Component 2: Streamlit Dashboard (`app.py`)

Run via `streamlit run app.py` on the server:

1. **Database Connection:** On load, connects to `predictions.db` to retrieve latest data.
2. **Main Status Dashboard:** High-level overview of all 50 units. Most recent prediction per unit displayed in a color-coded table (Green = Normal, Red = Abnormal).
3. **Detailed Unit View:** Dropdown (`st.selectbox`) selects a specific unit (e.g., `COE_ACU-02`).
4. **Historical Analysis:** Fetches prediction history for the selected unit. Displayed via `st.line_chart` or `st.dataframe` — allows maintenance staff to review sensor trends (coil temp, compressor current) leading up to abnormal predictions.

---

## 3.6 General Project Workflow

The project follows a phased workflow integrating product/model deployment and software development, represented in flowchart and Gantt chart form.

**Key phases:**

1. **Sensor calibration** — validity experiments for BME280, DS18B20, ACS712, ZMPT101B.
2. **Hardware deployment** — install nodes on 50 AC units across 3 locations.
3. **6-month data collection** — weekly visits, 10 trials per unit.
4. **Data preprocessing** — cleaning, splitting, transformation, PCA.
5. **Model development** — CNN for images + 5 classifiers for sensor data.
6. **Model evaluation** — confusion matrices, Friedman test comparison.
7. **Model deployment** — Streamlit dashboard + SQLite + Watchdog automation.

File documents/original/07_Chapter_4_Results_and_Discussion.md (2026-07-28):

# Chapter IV: Results and Discussion

> Note: This chapter reports the **completed sensor calibration experiments**. The 6-month data collection and ML model results are not yet included.

---

## 4.1 Sensor Validity Experiments

### 4.1.1 BME280 Calibration

**Methodology:** 100 samples collected in a controlled environment. Linear regression performed in R — comparing BME280 readings against a reference indoor thermometer.

#### Temperature Calibration

**R Input:**
```r
model = lm(temp_device ~ temp_sensor - 1)
summary(model)
```

**Results:** Statistically significant (p < 0.05).

**Calibration Equation:**
```
Reference = Sensor × 1.0294412
```

- R² = 1.0 (near-perfect fit)
- Residual standard error: 0.1329 on 99 DF
- F-statistic: 3.646×10⁶ (p < 2.2×10⁻¹⁶)

The BME280 readings are multiplied by 1.0294412 to align with the reference thermometer. This is a slope-only (no-intercept) model.

#### Humidity Calibration

**Results:** Statistically significant (p < 0.05).

**Calibration Equation:**
```
Reference = Sensor × 1.0579399
```

- R² = 0.9999
- Residual standard error: 0.3348 on 99 DF
- F-statistic: 1.496×10⁶ (p < 2.2×10⁻¹⁶)

### 4.1.2 DS18B20 Calibration

**Methodology:** 100 samples from each of two conditions — normal and cold environments. Combined dataset used for linear regression per probe (A, B, C).

#### Probe A Calibration

**R Input:**
```r
modelA = lm(Probe_A$Reference ~ Probe_A$Sensor)
summary(modelA)
```

**Calibration Equation:**
```
Reference = 1.701471 + 0.984997 × Sensor
```

- R² = 0.9839
- Residual standard error: 0.7182 on 198 DF
- F-statistic: 1.212×10⁴ (p < 2.2×10⁻¹⁶)
- Both intercept (1.701471) and slope (0.984997) are statistically significant.

#### Probe B Calibration

```
Reference = 1.637417 + 0.9783362 × Sensor
```

- R² = 0.9998
- Residual standard error: 0.07977 on 198 DF
- F-statistic: 1.236×10⁶ (p < 2.2×10⁻¹⁶)

#### Probe C Calibration

Uses the same formula as Probe B:
```
Reference = 1.637417 + 0.9783362 × Sensor
```

---

## Summary of Calibration Factors (Verified)

| Sensor | Formula | R² |
|---|---|-----|
| BME280 Temperature | `raw × 1.0294412` | ~1.0 |
| BME280 Humidity | `raw × 1.0579399` | ~1.0 |
| DS18B20 Probe A | `1.701471 + 0.984997 × raw` | 0.9839 |
| DS18B20 Probe B | `1.637417 + 0.9783362 × raw` | 0.9998 |
| DS18B20 Probe C | `1.637417 + 0.9783362 × raw` | (same as B) |

All models are statistically significant (p < 2.2×10⁻¹⁶). These factors are hardcoded in all sensor sketches across the firmware codebase.

---

## Gaps / Not Yet Available

- ACS712 current calibration results.
- ZMPT101B voltage calibration results.
- ESP32-CAM image classification model training results.
- 6-month sensor data collection.
- ML model comparison (RF, XGBoost, k-NN, RBF SVM, DNN, Hybrid RF+CNN).
- Friedman test statistical comparison.
- Streamlit dashboard implementation.

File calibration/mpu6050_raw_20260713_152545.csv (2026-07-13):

ax_raw | ay_raw | az_raw | gx_raw | gy_raw | gz_raw
-0.031125 | -0.335188 | 10.204087 | 0.030377 | 0.057289 | -0.019452
-0.081403 | -0.289698 | 10.163386 | 0.029977 | 0.058888 | -0.018119
-0.040701 | -0.265756 | 10.232818 | 0.031309 | 0.057956 | -0.017587
-0.026336 | -0.275333 | 10.199299 | 0.031176 | 0.055957 | -0.018119
-0.038307 | -0.248997 | 10.196905 | 0.031443 | 0.057156 | -0.018386
0.004788 | -0.284910 | 10.232818 | 0.032109 | 0.056757 | -0.017853
-0.016759 | -0.227449 | 10.201694 | 0.032109 | 0.056090 | -0.018519
0.124498 | -0.270545 | 10.144233 | 0.032109 | 0.052626 | -0.018386
0.052672 | -0.328006 | 10.196905 | 0.031709 | 0.055557 | -0.017853
0.019154 | -0.265756 | 10.151415 | 0.031842 | 0.056357 | -0.018519
0.007183 | -0.296881 | 10.204087 | 0.031309 | 0.056890 | -0.018919
0.038307 | -0.258574 | 10.177752 | 0.030377 | 0.054758 | -0.019585
-0.079009 | -0.232238 | 10.144233 | 0.030910 | 0.058222 | -0.018919
-0.026336 | -0.253785 | 10.170568 | 0.031975 | 0.055691 | -0.019585
-0.105345 | -0.234632 | 10.223241 | 0.032908 | 0.058089 | -0.019585
0.007183 | -0.234632 | 10.168175 | 0.031842 | 0.053825 | -0.018786
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

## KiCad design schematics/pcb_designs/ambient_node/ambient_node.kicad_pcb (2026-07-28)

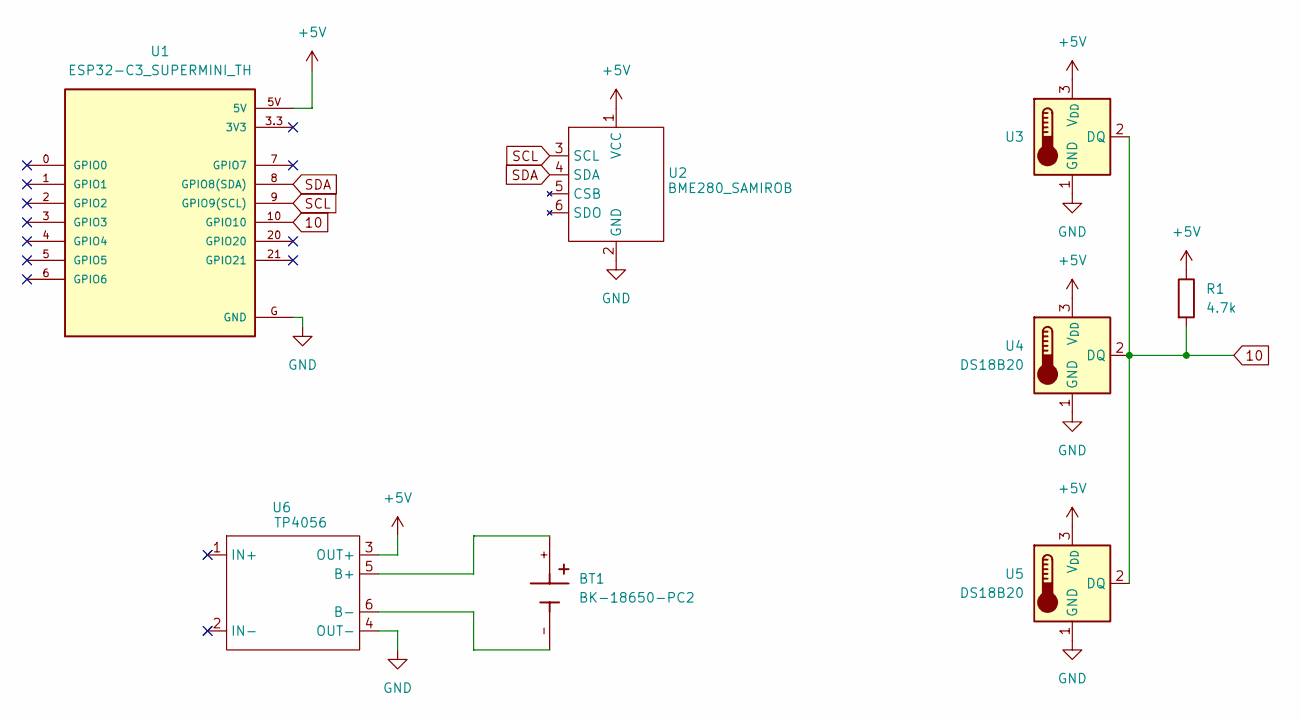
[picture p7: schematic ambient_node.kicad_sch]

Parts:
BT1: BK-18650-PC2; BAT_BK-18650-PC2; PARTREV F
R1: 4.7k; R_Axial_DIN0204_L3.6mm_D1.6mm_P5.08mm_Horizontal
U1: ESP32-C3_SUPERMINI_TH; MODULE_ESP32-C3_SUPERMINI_TH
U2: BME280_SAMIROB
U3, U4, U5: DS18B20; TO-92_Inline
U6: TP4056; TP4056-Module

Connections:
10: R1.2, U1.10 (GPIO10), U3.2 (DQ), U4.2 (DQ), U5.2 (DQ)
+5V: R1.1, U1.5V, U2.1 (VCC), U3.3 (V_{DD}), U4.3 (V_{DD}), U5.3 (V_{DD}), U6.3 (OUT+)
GND: U1.G (GND), U2.2 (GND), U3.1 (GND), U4.1 (GND), U5.1 (GND), U6.4 (OUT-)
unnamed: BT1.+, U6.5 (B+)
unnamed: BT1.-, U6.6 (B-)
SCL: U1.9 (GPIO9(SCL)), U2.3 (SCL)
SDA: U1.8 (GPIO8(SDA)), U2.4 (SDA)

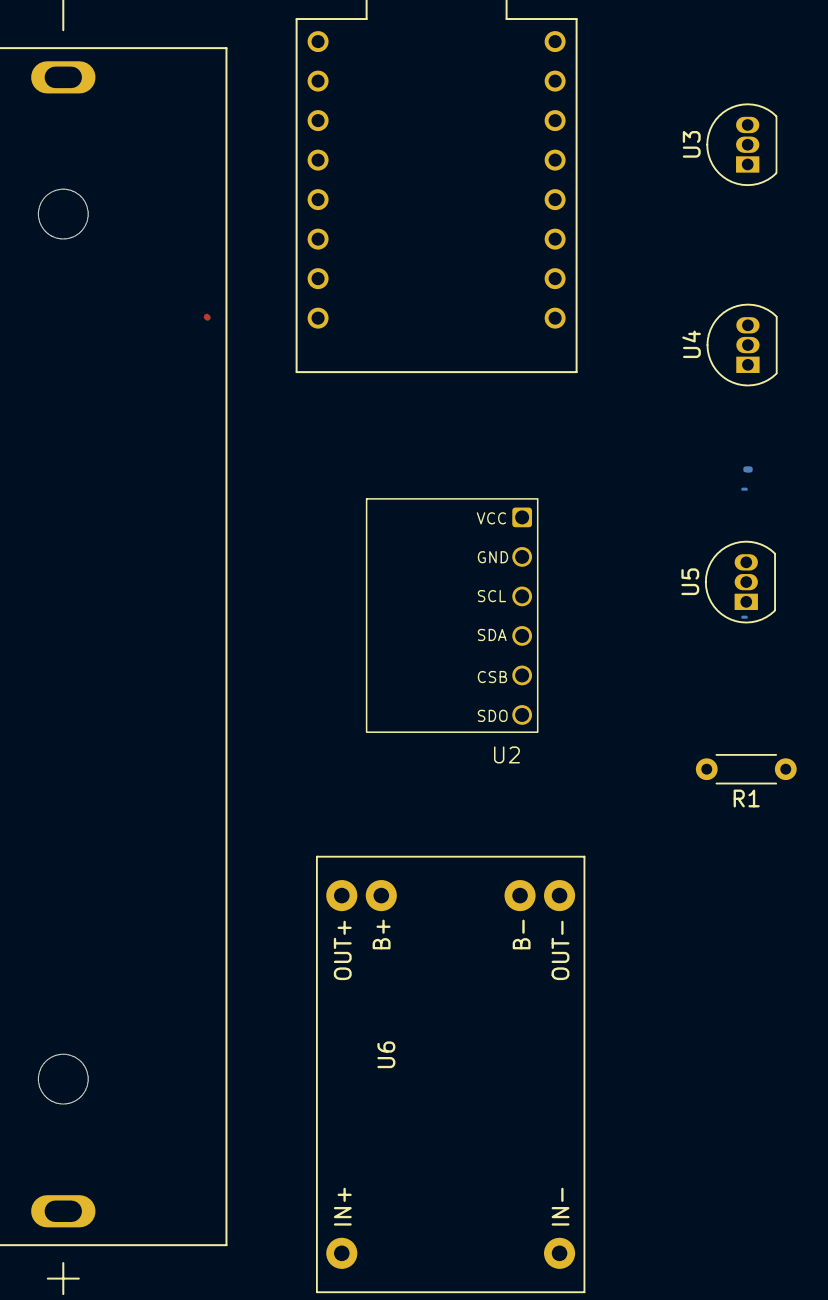
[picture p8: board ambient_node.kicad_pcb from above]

Board: 4 copper layers, 8 parts (0 on the bottom side), 7 nets.

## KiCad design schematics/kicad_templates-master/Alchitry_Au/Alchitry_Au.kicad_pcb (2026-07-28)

Board: 2 copper layers, 8 parts (0 on the bottom side), 3 nets, no tracks yet.

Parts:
B1, B2, B3, B4: Alchitry_Shield; Alchitry_Conn
H1, H2, H3, H4: MountingHole; 2m2ThroughHole

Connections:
+3V3: B1.B7, B1.B13, B1.B19, B1.B25, B1.B26, B1.B32, B1.B38, B1.B44, B2.B7, B2.B13, B2.B19, B2.B25, B2.B26, B2.B32, B2.B38, B2.B44, B3.B7, B3.B13, B3.B19, B3.B25, B3.B26, B3.B32, B3.B38, B3.B44, B4.B7, B4.B13, B4.B19, B4.B25, B4.B26, B4.B32, B4.B38, B4.B44
+5V: B1.B1, B1.B50, B2.B1, B2.B50, B3.B1, B3.B50, B4.B50
GND: B1.B4, B1.B10, B1.B16, B1.B22, B1.B29, B1.B35, B1.B41, B1.B47, B2.B4, B2.B10, B2.B16, B2.B22, B2.B29, B2.B35, B2.B41, B2.B47, B3.B4, B3.B10, B3.B16, B3.B22, B3.B29, B3.B35, B3.B41, B3.B47, B4.B4, B4.B10, B4.B16, B4.B22, B4.B29, B4.B35, B4.B41, B4.B47

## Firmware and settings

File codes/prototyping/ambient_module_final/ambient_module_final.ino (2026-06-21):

// Include the libraries we need
#include <OneWire.h>
#include <DallasTemperature.h>
#include <Wire.h>
#include <Adafruit_Sensor.h>
#include <Adafruit_BME280.h>

#define SEALEVELPRESSURE_HPA (1013.25)

Adafruit_BME280 bme;

// calibration factor (no intercept model)
const float CAL_FACTOR = 1.0294412;
const float Hum_Factor =  1.0579399;

// Data wire is connected to GPIO15
#define ONE_WIRE_BUS 10
// Setup a oneWire instance to communicate with a OneWire device
OneWire oneWire(ONE_WIRE_BUS);
// Pass our oneWire reference to Dallas Temperature sensor 
DallasTemperature sensors(&oneWire);

DeviceAddress sensorC = { 0x28, 0x2A, 0x70, 0x87, 0x0, 0x9, 0x59, 0xA0 };
DeviceAddress sensorA = { 0x28, 0xD9, 0x36, 0x87, 0x0, 0xD5, 0x4E, 0xF5 };
DeviceAddress sensorB= { 0x28, 0x67, 0xCC, 0x87, 0x0, 0xA, 0x7B, 0x3B };

void setup(void){
  Serial.begin(115200);
  sensors.begin();

    if (!bme.begin(0x76)) {
    Serial.println("Could not find a valid BME280 sensor, check wiring!");
    while (1);
  }

}

void loop(void){ 

  // raw sensor temperature
  float temp_raw = bme.readTemperature();
  float hum_raw = bme.readHumidity();
  // calibrated temperature (no intercept model)
  float temp_calibrated = CAL_FACTOR * temp_raw;
  float hum_calibrated = Hum_Factor * hum_raw;

  Serial.println("BME280 Readings");

  Serial.print("Calibrated Temperature = ");
  Serial.print(temp_calibrated);
  Serial.println(" *C");

  Serial.print("Humidity = ");
  Serial.print(hum_calibrated);
  Serial.println(" %");

  Serial.println("------------------");



  Serial.println("Probes Temperature Readings");
  sensors.requestTemperatures(); // Send the command to get temperatures

  Serial.print("Sensor A(*C): ");
  float rawTempA = sensors.getTempC(sensorA);
  float calibratedTempA = 1.701471 + (0.984997 * rawTempA);
  Serial.println(calibratedTempA); 

 
  Serial.print("Sensor B(*C): ");
  float rawTempB = sensors.getTempC(sensorB);
  float calibratedTempB = 1.6374170 + ( 0.9783362 * rawTempB);
  Serial.println(calibratedTempB); 

  
  Serial.print("Sensor C(*C): ");
  float rawTempC = sensors.getTempC(sensorC);
  float calibratedTempC = 1.6374170 + ( 0.9783362 * rawTempC);
  Serial.println(calibratedTempC); 
  Serial.println("------------------");
  
  delay(1000);
}

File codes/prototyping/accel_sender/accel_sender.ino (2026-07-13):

#include <WiFi.h>
#include <esp_now.h>
#include <esp_wifi.h>
#include <Adafruit_MPU6050.h>
#include <Adafruit_Sensor.h>

Adafruit_MPU6050 mpu;

// Hardcoded calibration offsets from mpu6050_raw_20260713_152545.csv
const float AX_BIAS = -0.005124;
const float AY_BIAS = -0.265409;
const float AZ_BIAS = 0.379842;

// Receiver MAC address
uint8_t receiverMac[] = {0xE0, 0x72, 0xA1, 0x6F, 0xF8, 0x6C};

const int wifiChannel = 11;
constexpr char WIFI_SSID[] = "PLDTHOMEFIBRd2228";

// Shared packet structure
typedef struct {
  uint8_t type;       // 0 = accel, 1 = ambient
  float data[6];      // payload
} EspNowPacket;

EspNowPacket packet;

void onDataSent(const wifi_tx_info_t *info, esp_now_send_status_t status) {
  Serial.print("Send: ");
  Serial.println(status == ESP_NOW_SEND_SUCCESS ? "OK" : "FAIL");
}

int32_t getWiFiChannel(const char *ssid) {
  if (int32_t n = WiFi.scanNetworks()) {
    for (uint8_t i = 0; i < n; i++) {
      if (!strcmp(ssid, WiFi.SSID(i).c_str())) {
        return WiFi.channel(i);
      }
    }
  }
  return 0;
}

void setup() {
  Serial.begin(115200);
  delay(1000);

  // Init MPU6050
  if (!mpu.begin()) {
    Serial.println("MPU6050 init failed");
    while (1) yield();
  }

  mpu.setAccelerometerRange(MPU6050_RANGE_4_G);
  mpu.setFilterBandwidth(MPU6050_BAND_21_HZ);

  Serial.println("MPU6050 ready");

  // WiFi + ESP-NOW
  WiFi.mode(WIFI_STA);

  int32_t channel = getWiFiChannel(WIFI_SSID);
  if (channel > 0) {
    esp_wifi_set_channel(channel, WIFI_SECOND_CHAN_NONE);
    Serial.print("Channel: ");
    Serial.println(channel);
  } else {
    esp_wifi_set_channel(wifiChannel, WIFI_SECOND_CHAN_NONE);
    Serial.print("Channel fallback: ");
    Serial.println(wifiChannel);
  }

  Serial.print("Sender MAC: ");
  Serial.println(WiFi.macAddress());

  if (esp_now_init() != ESP_OK) {
    Serial.println("ESP-NOW init failed");
    return;
  }

  esp_now_register_send_cb(onDataSent);

  esp_now_peer_info_t peerInfo = {};
  memcpy(peerInfo.peer_addr, receiverMac, 6);
  peerInfo.channel = wifiChannel;
  peerInfo.encrypt = false;

  if (esp_now_add_peer(&peerInfo) != ESP_OK) {
    Serial.println("Failed to add receiver peer");
    return;
  }

  Serial.println("Receiver peer added — sending in 3s");
  delay(3000);
}

void loop() {
  sensors_event_t a, g, temp;
  mpu.getEvent(&a, &g, &temp);

  float ax = a.acceleration.x - AX_BIAS;
  float ay = a.acceleration.y - AY_BIAS;
  float az = a.acceleration.z - AZ_BIAS;

  // Build packet
  packet.type = 0;
  packet.data[0] = ax;
  packet.data[1] = ay;
  packet.data[2] = az;
  packet.data[3] = 0;
  packet.data[4] = 0;
  packet.data[5] = 0;

  // Local print
  Serial.print("Accel: X=");
  Serial.print(ax, 3);
  Serial.print(" Y=");
  Serial.print(ay, 3);
  Serial.print(" Z=");
  Serial.print(az, 3);
  Serial.println(" m/s2");

  // Send
  esp_err_t result = esp_now_send(receiverMac, (uint8_t *)&packet, sizeof(packet));
  if (result != ESP_OK) {
    Serial.print("Send error: ");
    Serial.println(result);
  }

  delay(3000);
}

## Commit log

2026-06-21 Added Schematics and Thesis Proposal Document
    [BME 280 PROTOTYPE.fzz, BME 280 SOLO.fzz, DS18B20 EXPERIMENT.fzz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]
2026-06-30 Add MPU6050 test sketch & libraries
    - testing/mpu6050/: MPU6050 test sketch with Adafruit_MPU6050 library
    - Patched Adafruit_MPU6050 WHO_AM_I check to accept 0x70 (MPU6500/clone)
    - Added Adafruit_SSD1306 OLED library
    - Added MPU6050.fzz schematic
    - Added AGENTS.md with repo guidance
    - Removed root .gitignore (previously only ignored AGENTS.md)
    [MPU6050.fzz]
2026-07-08 Added Calibration for MPU6050
2026-07-13 Added Samples for MPU6050
    [mpu6050_raw_20260713_152545.csv]
2026-07-22 Added Roadmap with suggestions for each Chapter
    [#ACU MASTERLIST 2024NOV26.xlsx]
2026-07-28 Added Thesis Roadmap including Paper Overhaul and also added KICAD Schematics and PCB. Switched to Unsupervised Learning (anomaly detection)
    [AISLER-2Layer.kicad_pcb, AISLER-2Layer.sch, AISLER-4Layer.kicad_pcb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]
